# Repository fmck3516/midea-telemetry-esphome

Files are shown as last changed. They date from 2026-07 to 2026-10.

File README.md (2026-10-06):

# midea-telemetry-esphome

An [ESPHome](https://esphome.io/) component to feed test-port telemetry from Midea mini-splits and centrally ducted units into Home Assistant. No Home Assistant? It works standalone too: the dongle serves its own web dashboard and JSON API, with an optional InfluxDB + Grafana stack for long-term history.

It supports a variety of brands including MRCOOL, Cooper&Hunter, Pioneer, and Senville.

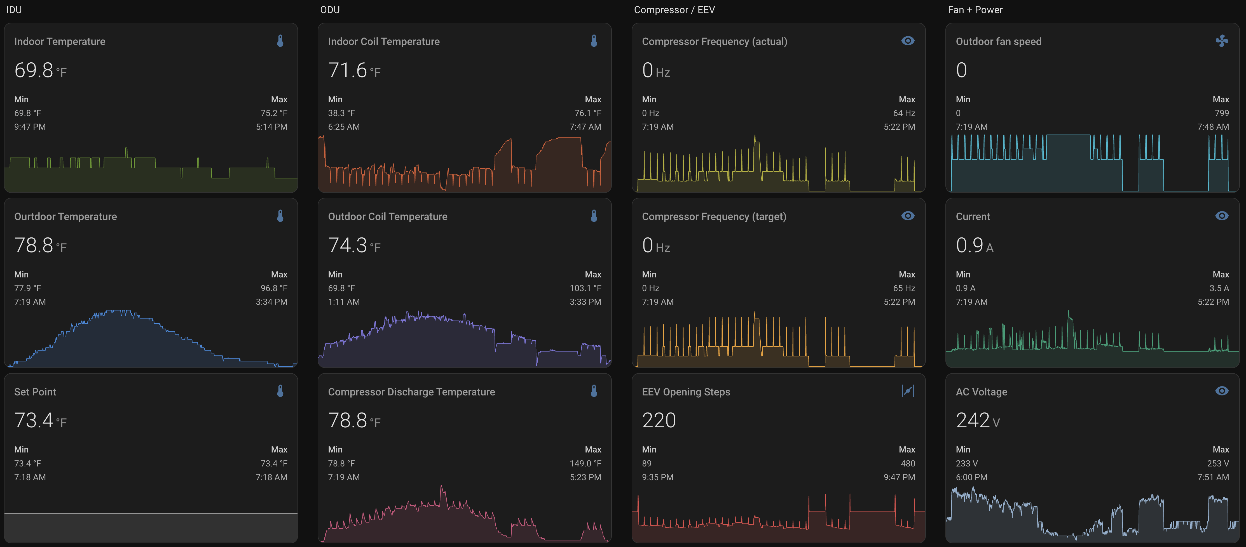
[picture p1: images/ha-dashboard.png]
Home Assistant Dashboard


## Support

Please use [GitHub Issues](https://github.com/fmck3516/midea-telemetry-esphome/issues) for bug reports and feature requests. 
For questions and general discussion, join the [Home Assistant Community thread](https://community.home-assistant.io/t/1015912). I'm active there.

## Compatibility

The dongle has been tested successfully with the following outdoor units:

| Brand | Outdoor Models | Type | 
|---|---|---|
| MRCOOL | DIY-12-HP-C-115C25 | single-zone mini-split |
| Cooper&Hunter | CH-HPR06F9-230VO, CH-N36LCU-230VO | single-zone mini-split |
| Senville | SENDC-36-HF-OG | centrally ducted unit |
| Pioneer | YN018GMFI20RPD | single-zone mini-split |
| ACiQ | ES-48Z-M6C | multi-zone mini-split |

Since Midea-made mini-splits and centrally ducted units are very similar across brands, many other units from brands like MRCOOL, Cooper&Hunter, Senville, Pioneer, Blueridge, etc. are supported as well. To confirm, look for a test port (a 4-pin JST connector labeled `TEST`) on your unit's wiring diagram or on the outdoor unit's control or auxiliary board.

**Multi-zone units:** the dongle runs on multi-zone systems, but four sensors (T1, T2, TT, Pr) have come back empty on the ACiQ multi-zone unit.

## Hardware

All you need is a **dual-core ESP32** and a level shifter. A dual core is required because the bus bit-banging runs in a dedicated FreeRTOS task. A full request/response cycle keeps the bus busy for ~380 ms, far too long to run on the main loop.

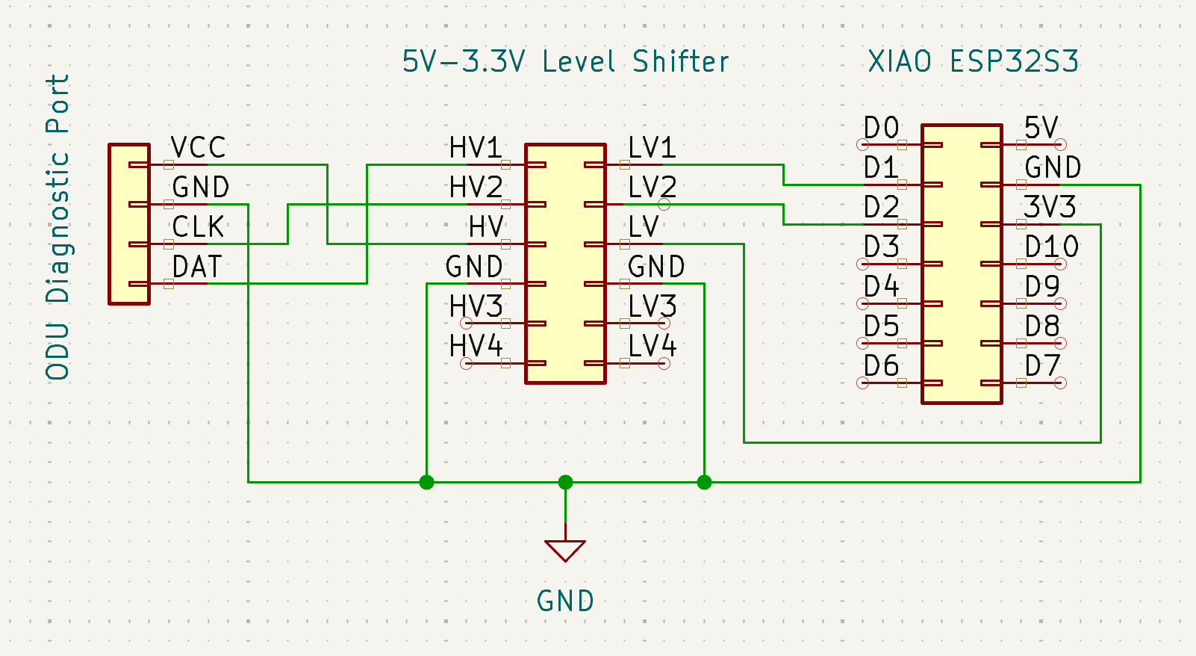
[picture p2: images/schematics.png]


Recommended hardware:
- [XIAO ESP32S3](https://www.amazon.com/dp/B0BYSB66S5)
- [3.3V–5V Level Shifter](https://www.amazon.com/dp/B07F7W91LC)

I used the following connector kits, but you can get away with a single 4-pin male JST-XH connector:
- [XH 2.54mm Connector Kit](https://www.amazon.com/dp/B08G18PWQ6)
- [2.54mm Connector 4 Pin Male Adapter Right Angle](https://www.amazon.com/dp/B0BMDQLR4Q)

### PCB & Enclosure

The KiCad project, schematic, and Gerber files live in [pcb/](pcb/) - a 2-layer board, 41.5 × 22 mm, 1.6 mm thick, with four M2 mounting holes. You solder in just three parts - the ODU connector, the level-shifter module, and the XIAO - and that's the whole build. FreeCAD sources plus STL and 3MF exports for the 3D-printable enclosure are in [enclosure/](enclosure/).

| PCB (top)  | PCB (bottom)  |
| --- | --- |
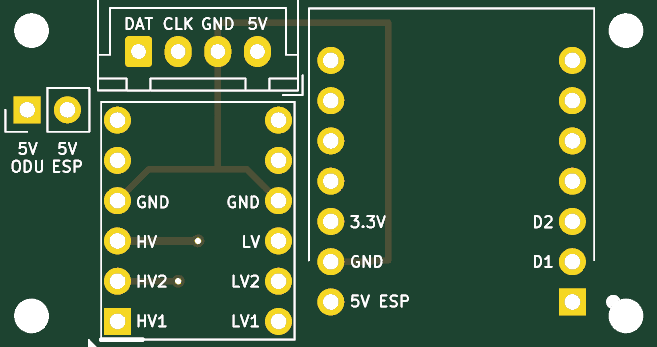
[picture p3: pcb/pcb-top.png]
Top
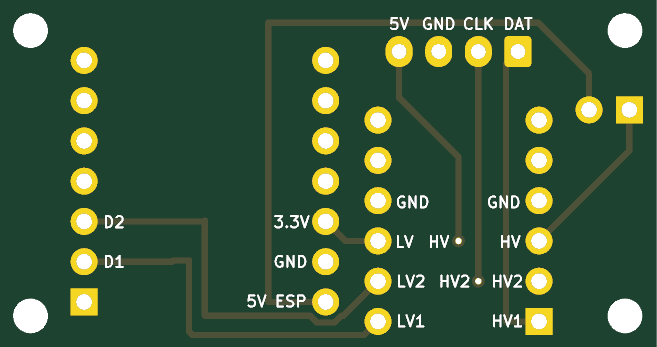
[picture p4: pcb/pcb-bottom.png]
Bottom
|  |  |

| Assembled dongle | Enclosure |
| --- | --- |
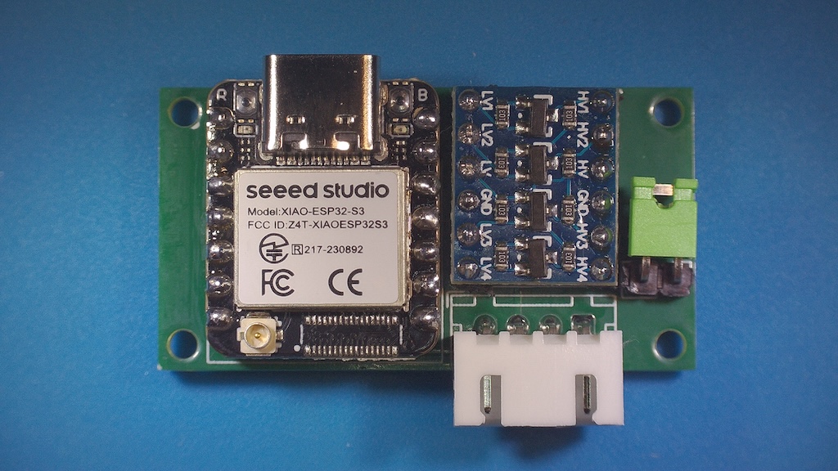
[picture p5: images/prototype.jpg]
Prototype
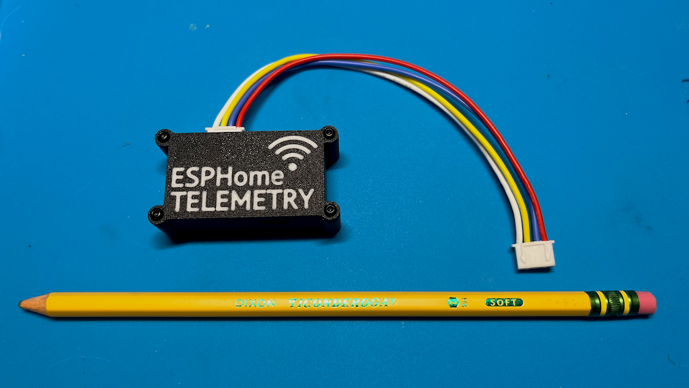
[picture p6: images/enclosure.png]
Enclosure
|  |  |

I've added a jumper that ties the test port's +5V to the XIAO's 5V pin. Use the jumper to run the board straight off the ODU with no USB cable. Leave it off if the board is connected to USB. I also recommend the use of a USB isolator since ground on the test port is not referenced to earth.

## Safety

The outdoor unit runs on mains voltage, and internal capacitors can retain a dangerous charge after being unplugged. Always

- turn off the breaker,
- pull the disconnect, and
- wait several minutes and/or verify capacitors are discharged

before performing the installation. Wear appropriate PPE. Consult a qualified electrician when in doubt.

## Installation

*(See [Safety](#safety) first if you're jumping straight to this section.)*

Remove the top panel of the ODU. You'll see the control board. Remove the screws securing the control board to the ODU, then detach the cables from the cable clamps so you can lift the board for access — there's no need to unplug the cables themselves. The test port on my units is located at the front of the board. Plug in the dongle, with the red wire facing toward you. Reattach the cables to the cable clamps and secure the board back to the ODU. There should be enough clearance to tuck the dongle into the service panel — this lets you access the dongle later without needing to remove the control board again. Reinstall the top panel.

| Control board | Test port |
| --- | --- |
| Install 1/4 | Install 2/4 |

| Dongle plugged in | Dongle tucked into service panel |
| --- | --- |
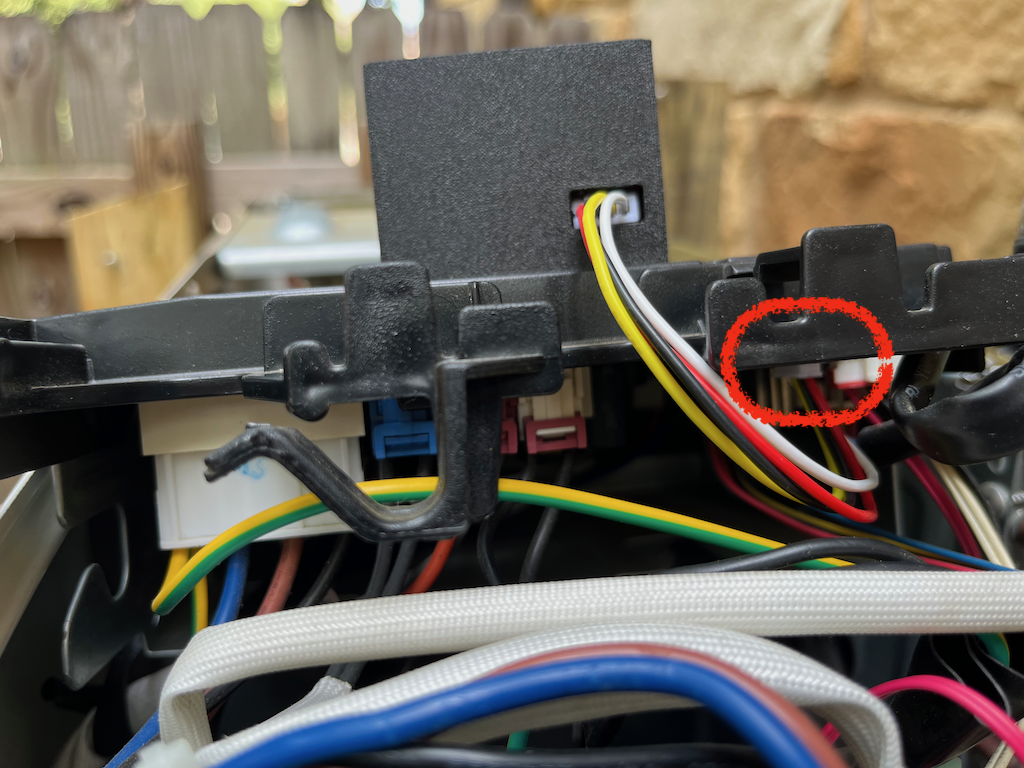
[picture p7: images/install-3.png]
Install 3/4
|  | Install 4/4 |

For a visual walkthrough, see [this installation video](https://www.youtube.com/watch?v=poEmSZnrnjs).

## First use

Upon first start, the dongle brings up a temporary WiFi hotspot so you can connect it to your WiFi network. Join the `midea-telemetry-esphome` network (password `midea-telemetry-esphome`) and provide your WiFi network's SSID and password in the popup that appears. Once connected, the dongle serves a webserver at `http://midea-telemetry.local` (useful if you don't run Home Assistant), and Home Assistant automatically detects it as a new ESPHome device.

| WiFi hotspot | WiFi setup |
| --- | --- |
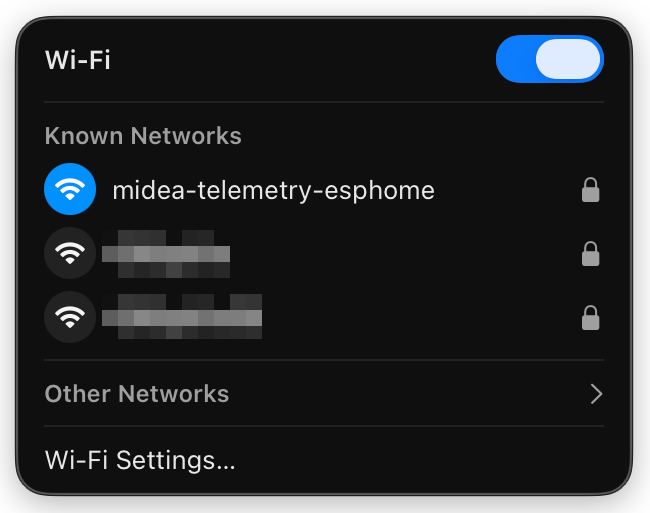
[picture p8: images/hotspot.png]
Hotspot
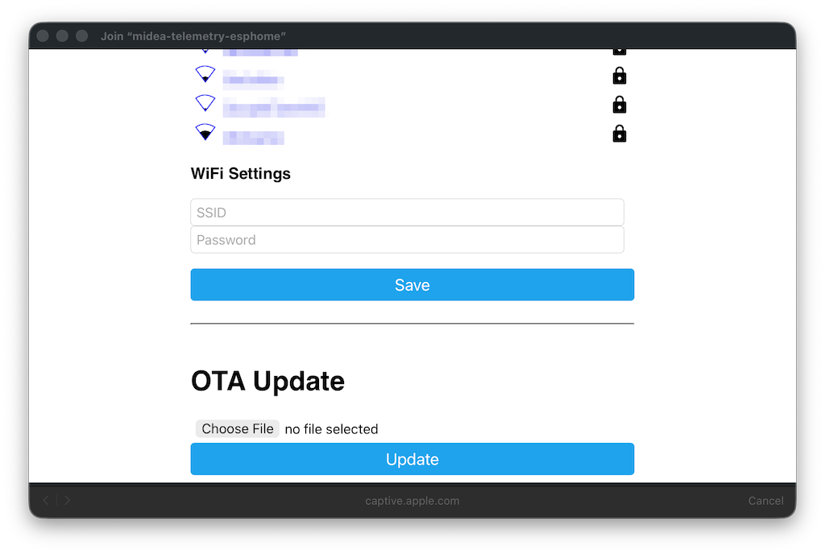
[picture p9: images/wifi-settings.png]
Wi-Fi settings
|  |  |

| On-board webserver | Home Assistant auto-discovery |
| --- | --- |
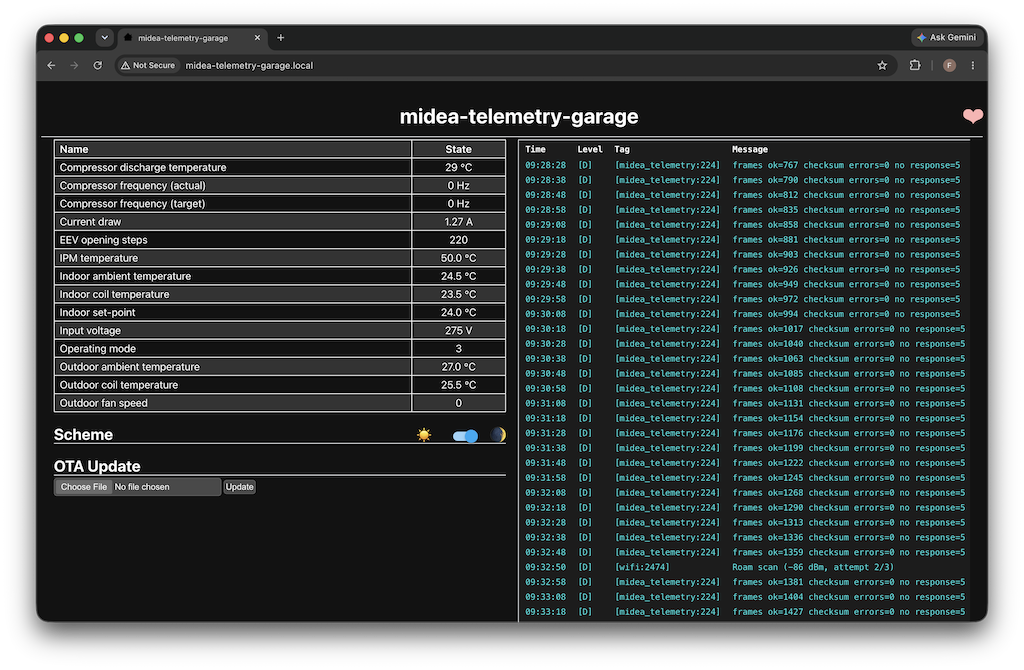
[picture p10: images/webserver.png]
Webserver
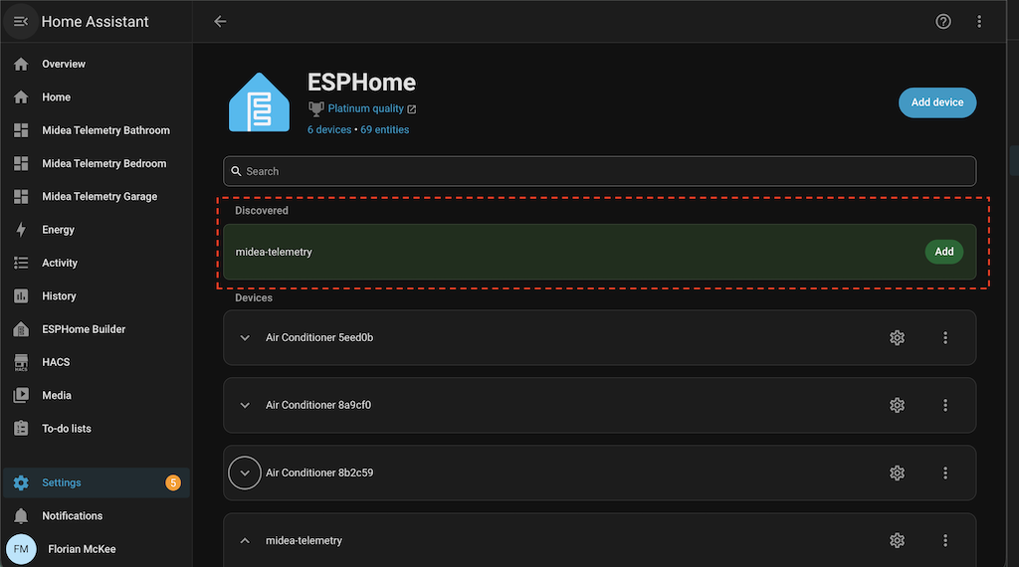
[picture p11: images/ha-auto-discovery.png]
Device auto discovery
|  |  |

## Configuration

See [example_midea_telemetry.yaml](example_midea_telemetry.yaml) for a complete configuration with every supported sensor. That file uses a local `components:` source, so it's flashable straight from a checkout of this repo; to pull the component remotely instead, switch the source to `github://fmck3516/midea-telemetry-esphome`.

## Flashing

Flash your ESP32 with `esphome`. On macOS:

```sh
brew install esphome
esphome run example_midea_telemetry.yaml
```

## Supported Sensors

The following sensors are currently supported. `Code` is the two-letter parameter code the Midea
service manuals use for the same value, so a reading here can be matched against the one the unit
shows on its own diagnostic display; `—` means the manuals define no code for that value.

| Code | Name | Unit |
|---|---|---|
| TT | `indoor_setpoint` | °C |
| T1 | `indoor_ambient_temperature` | °C |
| T2 | `indoor_coil_temperature` | °C |
| T3 | `outdoor_coil_temperature` | °C |
| T4 | `outdoor_ambient_temperature` | °C |
| TP | `discharge_temperature` | °C |
| — | `ipm_temperature` | °C |
| — | `operating_mode` | raw |
| oT | `compressor_frequency_indoor_target` | Hz |
| FT | `compressor_frequency_outdoor_target` | Hz |
| Fr | `compressor_frequency_actual_int` | Hz |
| Fr | `compressor_frequency_actual_float` | Hz |
| — | `compressor_frequency_outdoor_control` | Hz |
| Pr | `outdoor_fan_speed` | RPM |
| Lr | `eev_steps` | raw |
| dL | `current_draw` | A |
| Ac | `input_voltage` | V |
| Uo | `dc_bus_voltage` | V |
| — | `error_code_1` | bit mask for `E3, E0, P8, Eb, P6, PA, L3, L0` |
| — | `error_code_2` | bit mask for `E60, E61, L2, E2, E1, L1, P90, P91` |
| — | `error_code_3` | bit mask for `E80, E81, E1, E83, P0, P1, E5, P8` |
| — | `error_code_4` | bit mask for `P4, P6, PA, L5, L3, L2, E7` |

[FRAME-BYTES.md](FRAME-BYTES.md) documents each sensor in great detail.

## JSON endpoint

Add `expose_json_endpoint: true` to serve all mapped sensors and the underlying raw data as JSON. It needs the `web_server` component:

```yaml
web_server:
  port: 80

midea_telemetry:
  clk_pin: GPIO3
  dat_pin: GPIO2
  expose_json_endpoint: true
```

The endpoint is served at `/json` (e.g. `http://midea-telemetry.local/json`), independent of Home Assistant. This is useful for reverse engineering, scripting, and for using the device without Home Assistant.

## Long-term history (InfluxDB + Grafana)

For a permanent, Home-Assistant-independent history, [`influxdb-grafana/`](influxdb-grafana/) provides a ready-to-run Docker stack: Telegraf polls each dongle's `/json` endpoint and stores the raw frame bytes in InfluxDB v2, and Grafana decodes them into a provisioned dashboard. See [influxdb-grafana/README.md](influxdb-grafana/README.md).

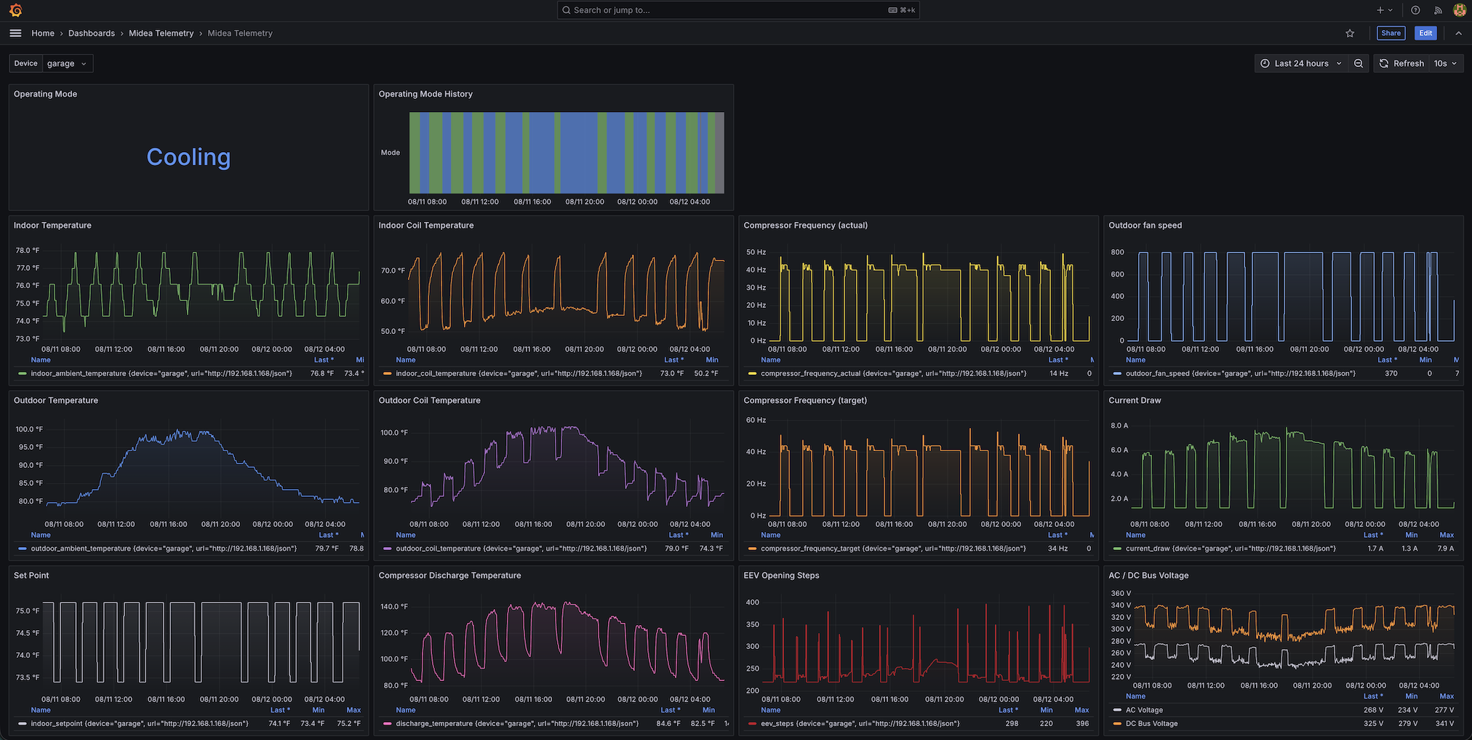
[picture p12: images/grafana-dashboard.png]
Grafana Dashboard


## Prior Art

I've documented the test-port protocol in great detail on Medium: [Reverse Engineering Midea's ODU Diagnostic Port](https://medium.com/@florian.mckee/reverse-engineering-mideas-odu-diagnostic-port-af603e159053). The firmware in this repository is based on those findings. Start there if you want to understand the protocol; the byte mappings and conversion formulas in the [Supported Sensors](#supported-sensors) table come straight from it.

## Warranty

This is a hobby project. I've permanently installed the telemetry module on all of my units without any problems. That said, use it at your own risk. I do not assume any liability if it causes damage to your equipment. See [LICENSE](LICENSE) for additional information.

## Disclaimer

Midea is a trademark of Midea Group. This is an independent, unofficial hobby project and is not affiliated with, authorized, endorsed by, or sponsored by Midea. The name is used only to describe which hardware the project interoperates with. All product names and trademarks are the property of their respective owners.

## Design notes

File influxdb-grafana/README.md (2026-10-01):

# InfluxDB + Grafana stack

A self-contained, permanent history for your midea-telemetry dongles. Telegraf
polls each dongle's `/json` endpoint and writes the **raw frame bytes** into
InfluxDB v2. Grafana decodes them into a provisioned dashboard. No Home
Assistant required.

```
 dongle /json  ──▶  Telegraf  ──▶  InfluxDB v2  ──▶  Grafana
 (every 10 s)     (raw bytes)    (bucket: midea)    (decodes in Flux)
```

## Prerequisites

- Docker with **Compose v2**, the `docker compose` plugin. Check with
  `docker compose version`. The old Python `docker-compose` 1.x is
  unmaintained and crashes with `KeyError: 'ContainerConfig'` whenever it
  recreates a container on current Docker Engine versions, such as when
  upgrading an image. On Ubuntu, install `docker-compose-v2`, or
  `docker-compose-plugin` from Docker's own apt repository.
- Each dongle built with `expose_json_endpoint: true` (pulls in `web_server`),
  reachable on your network. See the [main README](../README.md#json-endpoint).

## Setup

1. **Configure secrets.** Copy the env template and edit it — set a real Influx
   token and passwords:

   ```bash
   cp .env.example .env
   # generate a token:  openssl rand -hex 32
   ```

2. **List your dongles, then generate `telegraf.conf`.** Edit the `DEVICES`
   array at the top of [`gen-telegraf-conf.sh`](gen-telegraf-conf.sh) — one
   `"<url> <device-tag>"` per line — and run:

   ```bash
   ./gen-telegraf-conf.sh > telegraf.conf
   ```

   > ⚠️ **Required before step 3.** `telegraf.conf` is generated and
   > git-ignored (it holds your dongles' addresses), so a fresh clone does not
   > have one. Docker bind-mounts it, and if the file is missing it silently
   > creates a *directory* of that name — after which telegraf fails to start.
   > If that happens: `rm -rf telegraf.conf`, generate it, and bring the stack
   > back up.

   > ⚠️ **mDNS caveat.** Inside a bridged Docker container, `*.local` names do
   > **not** resolve. Use each dongle's **IP address** in `DEVICES`
   > (e.g. `http://192.168.1.42/json`), or — on a Linux host only — uncomment
   > `network_mode: host` for the telegraf service in `docker-compose.yml` to
   > share the host's mDNS resolver. Assign the dongles static DHCP leases so
   > the IPs stay put.

3. **Start it.**

   ```bash
   docker compose up -d
   ```

4. **Open Grafana** at http://localhost:3000, or `http://<host>:3000` from
   another machine on your network (log in with the Grafana
   credentials from `.env`). The **Midea Telemetry** dashboard is already there
   under the *Midea Telemetry* folder, with a **Device** dropdown at the top.

## What's provisioned

| Piece | Where |
|---|---|
| InfluxDB datasource (Flux) | `grafana/provisioning/datasources/influxdb.yml` |
| Dashboard provider | `grafana/provisioning/dashboards/dashboards.yml` |
| Dashboard | `grafana/dashboards/midea-telemetry.json` |

The dashboard charts every sensor from the [Supported Sensors table](../README.md#supported-sensors):
coil/ambient temps, discharge & IPM temps, the compressor-frequency family
(indoor/outdoor target, actual as int and float, and outdoor control),
outdoor fan speed & EEV
steps, input/DC-bus voltage, current draw, and set-point/operating mode. Below
those sit the [error codes](#error-codes), the "Compressor Frequency (extended)"
row (collapsed by default) and the [byte explorer](#byte-explorer). Everything
is filtered by the selected device.

The dashboard refreshes every 5 minutes. Telegraf still polls every 10 s, so
pick a shorter interval from Grafana's refresh dropdown when you want to watch
changes live.

## Network access

| Service | Reachable from | Port |
|---|---|---|
| Grafana | any machine on your network | `3000` |
| InfluxDB | this host only (`127.0.0.1`) | `8086` |
| Telegraf | nowhere, nothing is published | — |

Telegraf and Grafana reach InfluxDB over the compose network at
`http://influxdb:8086`, so InfluxDB doesn't need to be on your network. Its UI
and `tools/export-dashboard-data.py` still work on the host itself, where
`localhost:8086` is available. Run the export tool there.

Don't rely on a host firewall such as `ufw` to close a published port. Docker
adds its own firewall rules for published ports, and they bypass `ufw`. The
binding in `docker-compose.yml` decides who can connect.

To reach InfluxDB from another machine anyway, change its port to
`"8086:8086"` and run `docker compose up -d influxdb`. That exposes InfluxDB's
API and UI to your whole network.

Grafana answers anything that can reach the host on port 3000. Don't forward
that port on your router.

## How the dashboard decodes bytes

### What is stored

Telegraf writes one measurement, `midea_raw`, tagged by `device`. Each field is
one byte of one response frame, named `<frame>_<byte>`:

| Field | Meaning |
|---|---|
| `0x00_2` | response `0x00`, byte 2 |
| `0x05_2` | response `0x05`, byte 2 |
| … | bytes 2–8 of all seven responses, 49 fields |

Bytes 0, 1 and 9 are framing (header, response type, checksum) and are not
stored. What each byte means is documented in [FRAME-BYTES.md](../FRAME-BYTES.md).

Every byte comes from the same `/json` request, so all 49 share one timestamp.
That is what lets a value combine bytes from different frames, like the
compressor frequency float (`0x02[3]` + `0x05[2]`) or the current-draw gate on
`0x02[3]`.

The `dedup` processor drops a scrape in which no byte changed, and passes one
through at least every 5 minutes. Charts of a steady value therefore have fewer
points, not gaps.

> **Why one config entry per byte?** Two simpler Telegraf configs fail
> silently: the classic `json` parser drops arrays of plain numbers and writes
> nothing, and json_v2's `object` parser collapses each frame's array into one
> field that keeps only the last element (the checksum). Naming each byte is
> deterministic.

### How a panel decodes

Each panel's query:

1. filters to the bytes it needs;
2. has InfluxDB keep only the **last sample per chart window** (the stat cards
   keep only the latest sample; the [error-code panels](#error-codes) keep the
   window's highest sample instead, for the reason given there);
3. pivots those samples into one row per timestamp;
4. applies the formula from the byte's block in
   [FRAME-BYTES.md](../FRAME-BYTES.md);
5. names the result after the firmware sensor, so legends and exported CSV
   columns keep the sensor names.

Step 2 has to come before the pivot. Up to that point InfluxDB's storage
engine runs the query itself. From the pivot on, every row is processed one at
a time, and doing that for every raw point kept `influxd` at about four CPU
cores while the dashboard still refreshed every 10 s.

It keeps the *last* sample rather than the average because all 49 bytes of a
scrape are written together. The last sample of each byte in a window therefore
comes from the same scrape, so the two halves of a 16-bit value, and a reading
and its current-draw gate, always belong together. Averaging each byte on its
own would mix scrapes.

For example, `indoor_ambient_temperature`:

```flux
import "math"

from(bucket: "${bucket}")
  |> range(start: v.timeRangeStart, stop: v.timeRangeStop)
  |> filter(fn: (r) => r._measurement == "midea_raw" and r.device == "${device}")
  |> filter(fn: (r) => r._field == "0x00_2")
  |> aggregateWindow(every: v.windowPeriod, fn: last, createEmpty: false)
  |> pivot(rowKey: ["_time"], columnKey: ["_field"], valueColumn: "_value")
  |> filter(fn: (r) => exists r["0x00_2"])
  |> map(fn: (r) => {
        b = float(v: r["0x00_2"])
        // NTC β-model, rounded to the nearest 0.5 °C; 0 and 255 are fault codes
        ntc = (b) => math.round(x: (1.0 / (1.0 / 298.15 + math.log(x: 0.81 * (255.0 - b) / b) / 4150.0) - 273.15) * 2.0) / 2.0

        return {_time: r._time, _field: "indoor_ambient_temperature", _value: if b == 0.0 then -66.0 else if b == 255.0 then 255.0 else ntc(b: b)}
     })
  |> group(columns: ["_field"])
  |> sort(columns: ["_time"])
  |> map(fn: (r) => ({ r with _value: r._value * 1.8 + 32.0 }))
```

Because the formula lives in the query, fixing a decode needs no reflash. The
whole history is recomputed the next time the panel loads.

**Keep the decodes in step with the firmware.** Home Assistant and the dongle's
own web page still use the firmware's decode, so the same formula exists in two
places. A decode change updates both, plus
[FRAME-BYTES.md](../FRAME-BYTES.md#keeping-this-file-current).

Known differences from the firmware:

- **Charts show the last reading in each window**, not the average. The two
  only differ when a window spans several scrapes, which happens when zoomed
  far out.
- **Current draw** is 0.01 A higher on six raw values (10, 30, 70, 130, 140,
  150). The firmware computes in float32, lands just under a whole hundredth
  and truncates. Flux computes in float64 and gets the exact value. Every
  other decode matches the firmware for all 256 byte values.
- **Stale frames** show as a flat line, not a gap. The firmware reports a
  decoded sensor as unavailable once its frame is 60 s old. `/json` keeps
  serving the last raw frame received.

### Error codes

The **Error Codes** row charts each error bit field of response `0x02` over
time, one panel per byte, titled with the codes that byte carries:

| Panel | Byte | Sensor |
|---|---|---|
| Error Code E3, E0, P8, Eb, P6, PA, L3, L0 | `0x02[4]` | `error_code_1` |
| Error Code E60, E61, L2, E2, E1, L1, P90, P91 | `0x02[5]` | `error_code_2` |
| Error Code E80, E81, E1, E83, P0, P1, E5, P8 | `0x02[6]` | `error_code_3` |
| Error Code P4, P6, PA, L5, L3, L2, E7 | `0x02[7]` | `error_code_4` |

Charts rather than single values, so a fault can be lined up in time against
the temperature, frequency and current panels above — a `P0` means more once
you can see what the compressor was doing in the minutes before it. The legend
carries last/min/max, so the worst value over the selected range is readable
without hunting along the line.

The codes are listed from bit 0 (value 1) up to bit 7 (value 128), so a panel
reading `20` has bits 2 and 4 set — the third and fifth code in its title.
[FRAME-BYTES.md](../FRAME-BYTES.md#response-type-0x02) spells out every bit.

**These four panels keep the highest sample per window**, not the last one
like every other panel. A bit field is not a quantity: averaging or taking the
last sample of a window would hide a fault that set and cleared inside it, and
an average would invent byte values that never occurred (a window holding `0`
and `16` would read `8`, which is a different code entirely). `max` always
reports a byte that was really seen.

The row is **expanded by default**: a fault that came and went is easy to miss
behind a collapsed row. On a healthy unit all four charts stay flat at `0`, so
collapse it if you would rather have the vertical space.

### Byte explorer

The bottom of the dashboard charts undecoded bytes, for hunting new mappings.
Two variables drive it:

| Variable | Values |
|---|---|
| `Message` (`frame`) | `0x00` … `0x06` |
| `Byte` (`byte`) | `2` … `8` |

A repeating **Message** row per response frame holds one chart per byte, four
to a line, each titled like **`0x00[2]`**. Narrow either dropdown to focus on
one message, or on the same byte across all messages.

## Export the dashboard data

[`tools/export-dashboard-data.py`](../tools/export-dashboard-data.py) writes the
data behind **every chart on the dashboard** to CSV — one file per chart, per
device — for the last *N* days:

```bash
./tools/export-dashboard-data.py --days 7
```

```
exports/2025-08-30T09-14-02/
├── manifest.json                  # panel → file, columns, and the Flux run
├── bedroom/
│   ├── t1-indoor-temperature.csv  # time,indoor_ambient_temperature
│   ├── mode-set-point.csv         # multi-target panels get one column each
│   └── 0x00-2.csv                 # byte explorer charts too
└── garage/…
```

It reads the queries out of `grafana/dashboards/midea-telemetry.json` and runs
them against InfluxDB directly, so Grafana does not have to be up — only
InfluxDB. Credentials come from `.env` (override with `$INFLUX_*` or the flags).
Standard library only; no `pip install`.

| Flag | Default |
|---|---|
| `--days N` | `7` — how far back to export (fractional days are fine) |
| `--device TAG` | every device in the bucket; repeatable |
| `--interval` | `auto` (~2000 points/series); set `1m`, `5m`, … to fix it |
| `--out DIR` | `tools/exports/<timestamp>` |
| `--dry-run` | print the Flux queries instead of running them |

The hidden per-panel target that pins the Y axis to zero (the `${ymin}` helper)
is skipped — it carries no data.

## Verify data is flowing

```bash
docker compose logs -f telegraf     # should show no connection errors
```

On the host, in the InfluxDB UI (http://localhost:8086) → *Data Explorer*, query the `midea`
bucket for measurement `midea_raw`. You should see fields `0x00_2` … `0x06_8`,
tagged by `device`. Or list the field keys in the script editor:

```flux
import "influxdata/influxdb/schema"

schema.measurementFieldKeys(bucket: "midea", measurement: "midea_raw")
```

## Retention

`INFLUX_RETENTION` in `.env` controls how long data is kept (`0s` = forever).
Change it before first boot, or adjust the bucket's retention later in the
InfluxDB UI.

## Common tweaks

- **Poll interval:** `interval` in the `[agent]` block of
  `gen-telegraf-conf.sh`, then regenerate. Keep it ≥ the dongle's
  `update_interval` so you're not polling faster than new frames arrive.
- **Change the bucket name:** update `INFLUX_BUCKET` in `.env` **and** the hidden
  `bucket` constant in the dashboard (Dashboard settings → Variables → `bucket`).
- **Add/remove a dongle:** edit `DEVICES` in `gen-telegraf-conf.sh`, then
  `./gen-telegraf-conf.sh > telegraf.conf && docker compose restart telegraf`.
  New devices appear in the dropdown automatically.
- **Change a decode:** edit the panel's Flux in
  `grafana/dashboards/midea-telemetry.json`, and keep it in step with the
  firmware (see [How a panel decodes](#how-a-panel-decodes)).

## Reset

```bash
docker compose down          # stop, keep data
docker compose down -v       # stop and delete all stored data
```

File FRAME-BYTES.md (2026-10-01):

# Frame bytes

What every byte of every test-port message means, as far as it is known, and how the decoded
ones are converted. The [Supported Sensors](README.md#supported-sensors) table in the README only
lists the sensors. Look here for which bytes a sensor comes from, or what an unmapped byte like
[`0x03[4]`](#payload-0x034) might be.

Bytes are written `0x<type>[<index>]`, the notation used by the README, `/json`, the Grafana
byte explorer and the [raw byte sensors](README.md#raw-frame-bytes-optional). The index is
0-based within the 10-byte frame.

## Byte map

Every response byte at a glance, by response type (rows) and byte index (columns). Each cell links
to the block that describes the byte.

| Type | 0 | 1 | 2 | 3 | 4 | 5 | 6 | 7 | 8 | 9 |
|---|:-:|:-:|:-:|:-:|:-:|:-:|:-:|:-:|:-:|:-:|
| [`0x00`](#response-type-0x00) | [F](#frame-layout) | [F](#frame-layout) | [✅](#payload-0x002) | [✅](#payload-0x003) | [✅](#payload-0x004) | [✅](#payload-0x005) | [✅](#payload-0x006) | [✅](#payload-0x007) | [✅](#payload-0x008) | [F](#frame-layout) |
| [`0x01`](#response-type-0x01) | [F](#frame-layout) | [F](#frame-layout) | [✅](#payload-0x012) | [✅](#payload-0x013) | [✅](#payload-0x014) | [✅](#payload-0x015) | [✅](#payload-0x016) | [✅](#payload-0x017) | [🟡](#payload-0x018) | [F](#frame-layout) |
| [`0x02`](#response-type-0x02) | [F](#frame-layout) | [F](#frame-layout) | [✅](#payload-0x022) | [✅](#payload-0x023) | [✅](#payload-0x024) | [✅](#payload-0x025) | [✅](#payload-0x026) | [✅](#payload-0x027) | [✅](#payload-0x028) | [F](#frame-layout) |
| [`0x03`](#response-type-0x03) | [F](#frame-layout) | [F](#frame-layout) | [⬜](#payload-0x032) | [⬜](#payload-0x033) | [🟡](#payload-0x034) | [🟡](#payload-0x035) | [✅](#payload-0x036) | [⬜](#payload-0x037) | [⬜](#payload-0x038) | [F](#frame-layout) |
| [`0x04`](#response-type-0x04) | [F](#frame-layout) | [F](#frame-layout) | [🟡](#payload-0x042) | [⬜](#payload-0x043) | [⬜](#payload-0x044) | [⬜](#payload-0x045) | [🟡](#payload-0x046) | [✅](#payload-0x047) | [✅](#payload-0x048) | [F](#frame-layout) |
| [`0x05`](#response-type-0x05) | [F](#frame-layout) | [F](#frame-layout) | [✅](#payload-0x052) | [🟡](#payload-0x053) | [⬜](#payload-0x054) | [⬜](#payload-0x055) | [⬜](#payload-0x056) | [⬜](#payload-0x057) | [⬜](#payload-0x058) | [F](#frame-layout) |
| [`0x06`](#response-type-0x06) | [F](#frame-layout) | [F](#frame-layout) | [⬜](#payload-0x0620x068) | [⬜](#payload-0x0620x068) | [⬜](#payload-0x0620x068) | [⬜](#payload-0x0620x068) | [⬜](#payload-0x0620x068) | [⬜](#payload-0x0620x068) | [⬜](#payload-0x0620x068) | [F](#frame-layout) |

| Mark | Meaning |
|---|---|
| F | Framing: header, type or checksum. See [Frame layout](#frame-layout) |
| ✅ | Decoded and exposed as a Home Assistant sensor |
| 🟡 | Meaning proposed or partially known, but not exposed as a sensor |
| ⬜ | Unknown |

## Frame layout

Every message, in both directions, is 10 bytes, sent LSB-first:

| Byte | Request (dongle → ODU) | Response (ODU → dongle) |
|---|---|---|
| 0 | `0xAA`, the header for a message from the tester | `0x55`, the header for a message from the ODU |
| 1 | Request type, `0x00`–`0x03` | Response type, `0x00`–`0x06` |
| 2–8 | Payload | Payload |
| 9 | Checksum | Checksum |

**Checksum:** all ten bytes sum to zero modulo 256, so `checksum = (256 − sum(bytes 0–8) % 256) % 256`.
The firmware drops a response that fails this check. A response of ten `0xFF` bytes means the ODU
did not answer.

**Multi-byte values** are little-endian: the lower index is the low byte.

**Requests and responses are not paired.** The ODU steps through the seven response types on its
own, so a response is identified by its type byte, not by the request that triggered it.

## Requests

The dongle replays the four requests of Midea's handheld inverter tester, byte for byte. Their
payloads are constant, and nothing is known about what they mean.

| Type | Frame | Payload |
|---|---|---|
| `0x00` | `AA 00 00 00 00 00 00 00 00 56` | all `0x00` |
| `0x01` | `AA 01 00 00 00 00 00 00 00 55` | all `0x00` |
| `0x02` | `AA 02 00 00 00 00 FF 00 00 55` | all `0x00` except byte 6 = `0xFF` |
| `0x03` | `AA 03 00 00 00 00 00 00 00 53` | all `0x00` |

`0x02[6]` = `0xFF` is the only non-zero payload byte.

## Responses

Bytes 0, 1 and 9 of every response are **framing**, as shown above. The blocks below cover bytes 2–8.

### Response Type `0x00`

Every payload byte of `0x00` is decoded.

#### Payload `0x00[2]`

| | |
|---|---|
| Meaning | Indoor ambient temperature |
| HA Entity | `indoor_ambient_temperature` |
| Midea Code | T1 |
| Encoding | [NTC β-model](#ntc-thermistors) |
| Confidence | High |
| Evidence | Encoding reverse-engineered using Midea's Inverter Tester |
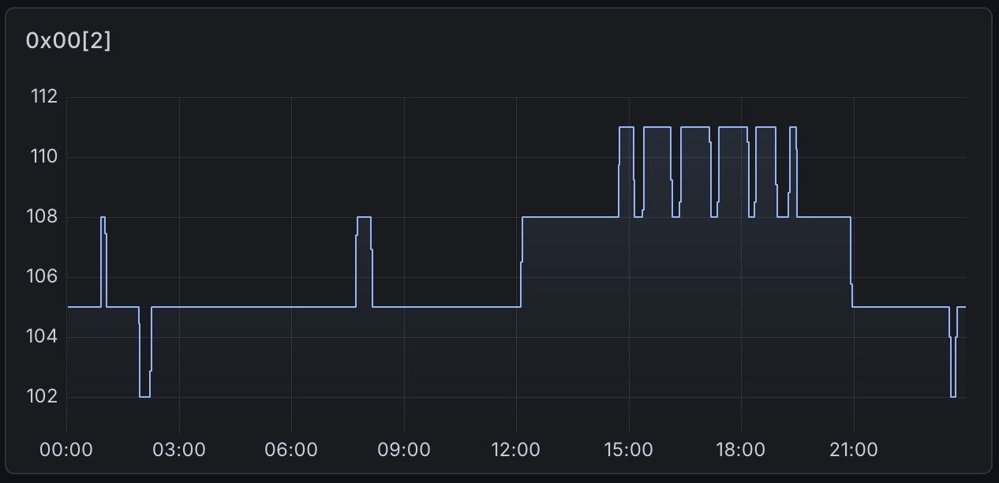
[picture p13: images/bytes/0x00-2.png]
| Chart (raw) |  |

#### Payload `0x00[3]`

| | |
|---|---|
| Meaning | Indoor coil temperature |
| HA Entity | `indoor_coil_temperature` |
| Midea Code | T2 |
| Encoding | [NTC β-model](#ntc-thermistors) |
| Confidence | High |
| Evidence | Encoding reverse-engineered using Midea's Inverter Tester |
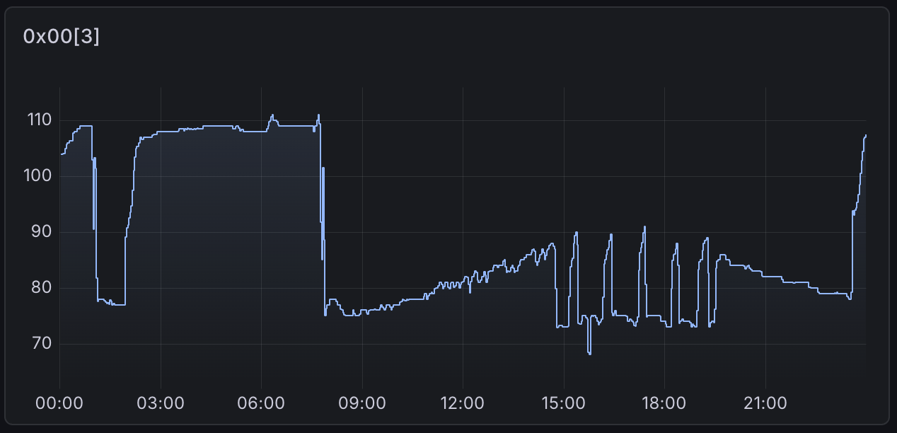
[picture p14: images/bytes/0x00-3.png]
| Chart (raw) |  |

#### Payload `0x00[4]`

| | |
|---|---|
| Meaning | Outdoor coil temperature |
| HA Entity | `outdoor_coil_temperature` |
| Midea Code | T3 |
| Encoding | [NTC β-model](#ntc-thermistors) |
| Confidence | High |
| Evidence | Encoding reverse-engineered using Midea's Inverter Tester |
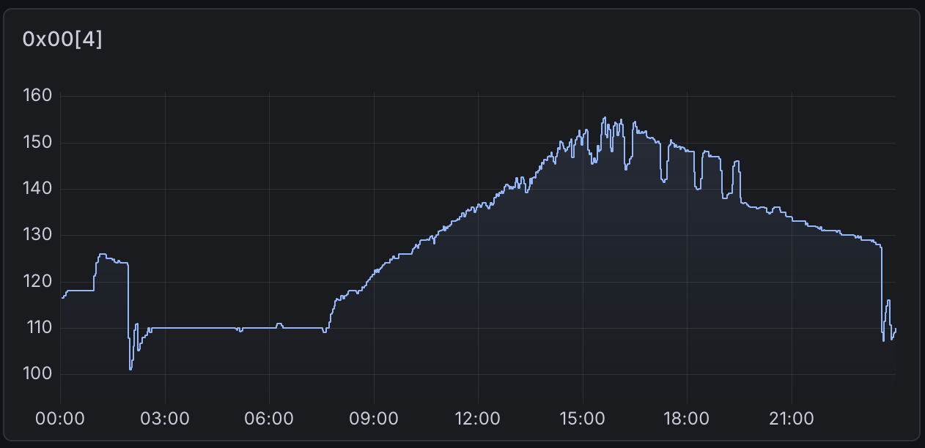
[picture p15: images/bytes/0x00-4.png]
| Chart (raw) |  |

#### Payload `0x00[5]`

| | |
|---|---|
| Meaning | Outdoor ambient temperature |
| HA Entity | `outdoor_ambient_temperature` |
| Midea Code | T4 |
| Encoding | [NTC β-model](#ntc-thermistors) |
| Confidence | High |
| Evidence | Encoding reverse-engineered using Midea's Inverter Tester |
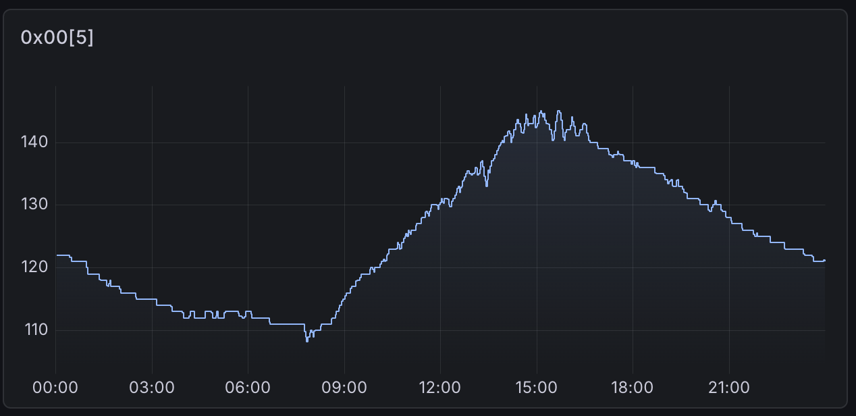
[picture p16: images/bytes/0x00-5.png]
| Chart (raw) |  |

#### Payload `0x00[6]`

| | |
|---|---|
| Meaning | Compressor discharge temperature |
| HA Entity | `discharge_temperature` |
| Midea Code | TP |
| Encoding | [Steinhart–Hart](#discharge-thermistor) |
| Confidence | High |
| Evidence | Encoding reverse-engineered using Midea's Inverter Tester |
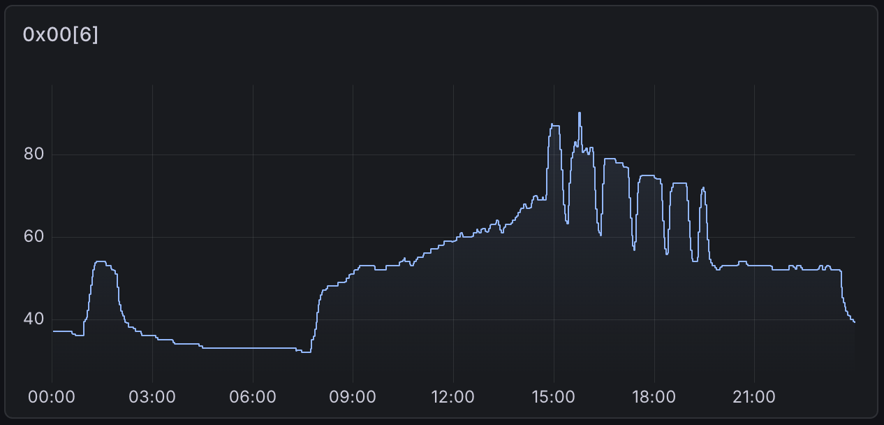
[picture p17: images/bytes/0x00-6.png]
| Chart (raw) |  |

#### Payload `0x00[7]`

| | |
|---|---|
| Meaning | Outdoor fan speed, low byte |
| HA Entity | `outdoor_fan_speed` |
| Midea Code | Pr |
| Encoding | uint16 LE with [`0x00[8]`](#payload-0x008) |
| Confidence | High |
| Evidence | Encoding reverse-engineered using Midea's Inverter Tester |
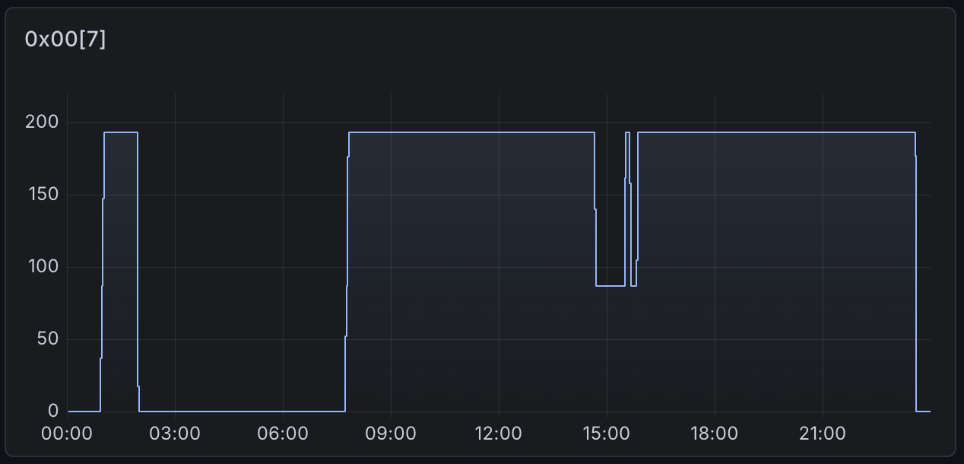
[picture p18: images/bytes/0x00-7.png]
| Chart (raw) |  |

#### Payload `0x00[8]`

| | |
|---|---|
| Meaning | Outdoor fan speed, high byte |
| HA Entity | `outdoor_fan_speed` |
| Midea Code | Pr |
| Encoding | uint16 LE with [`0x00[7]`](#payload-0x007) |
| Confidence | High |
| Evidence | Encoding reverse-engineered using Midea's Inverter Tester |
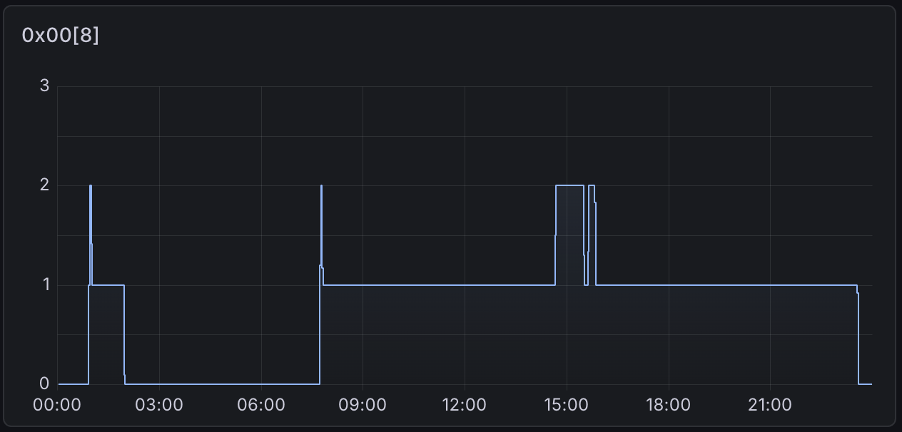
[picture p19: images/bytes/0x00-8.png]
| Chart (raw) |  |

### Response Type `0x01`

#### Payload `0x01[2]`

| | |
|---|---|
| Meaning | Compressor current draw |
| HA Entity | `current_draw` |
| Midea Code | dL |
| Encoding | `0.117 · b + 0.92` A, truncated to 0.01 A, gated on the compressor frequency |
| Confidence | High |
| Evidence | Encoding reverse-engineered using Midea's Inverter Tester. The byte only carries a meaningful current while the compressor runs. When it is stopped (unit OFF or FAN ONLY) the byte sits at a per-unit floor (3 on the 115V MRCOOL, 0 on the 220V Cooper & Hunter) that the formula would misread as ~1 A. So `current_draw` reports a ~0.2 A standby baseline. This is the value I measured with a clamp meter whenever `compressor_frequency_actual_int` (`0x02[3]`) is 0 on my mini-splits. |
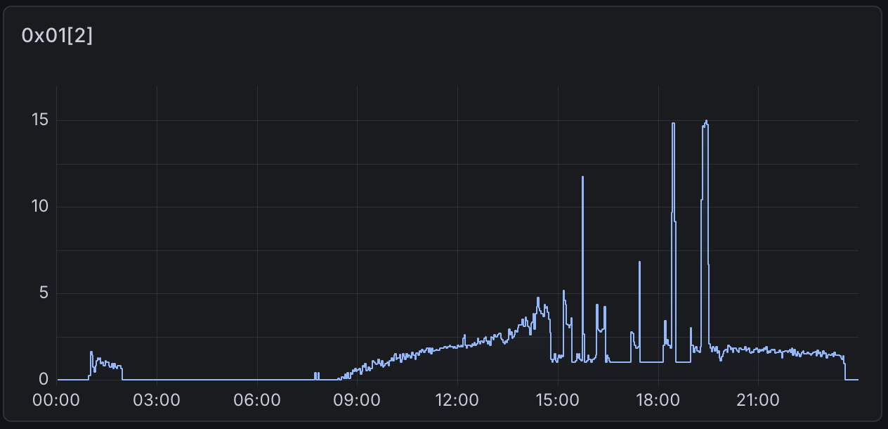
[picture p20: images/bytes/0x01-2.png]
| Chart (raw) |  |

#### Payload `0x01[3]`

| | |
|---|---|
| Meaning | AC input voltage |
| HA Entity | `input_voltage` |
| Midea Code | Ac |
| Encoding | `⌊b · 32/25 + 40⌋` V |
| Confidence | High |
| Evidence | Encoding reverse-engineered using Midea's Inverter Tester. |
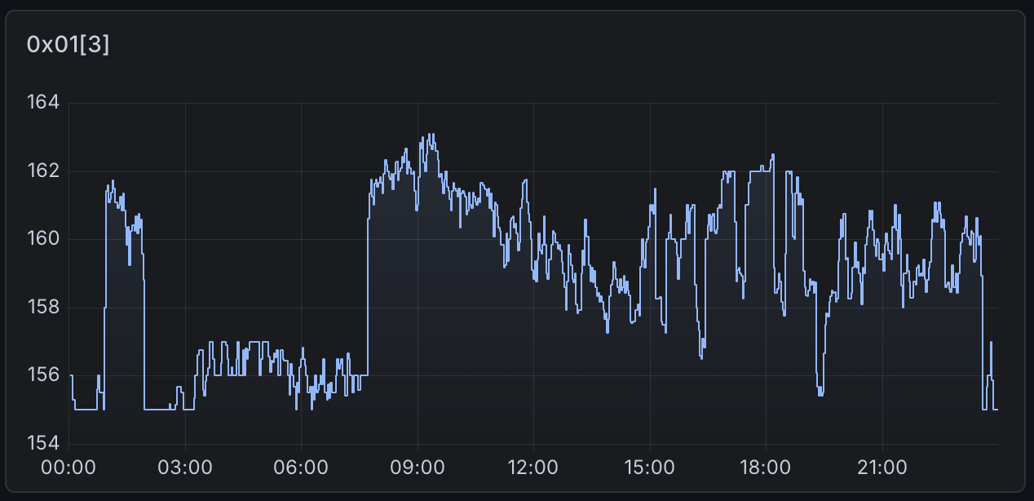
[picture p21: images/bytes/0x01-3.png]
| Chart (raw) |  |

#### Payload `0x01[4]`

| | |
|---|---|
| Meaning | IPM temperature |
| HA Entity | `ipm_temperature` |
| Midea Code | — |
| Encoding | [NTC β-model](#ntc-thermistors) |
| Confidence | Medium |
| Evidence | Not confirmed against a service display. It only seems to carry the IPM temperature on some units: [forum](https://community.home-assistant.io/t/1015912/17), [forum](https://community.home-assistant.io/t/1015912/60), [forum](https://community.home-assistant.io/t/1015912/79) |
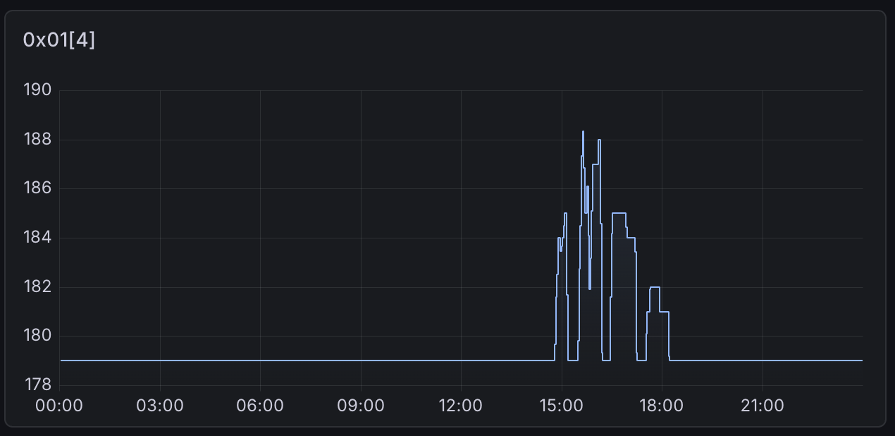
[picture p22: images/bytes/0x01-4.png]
| Chart (raw) |  |

#### Payload `0x01[5]`

| | |
|---|---|
| Meaning | EEV opening steps, low byte |
| HA Entity | `eev_steps` |
| Midea Code | Lr |
| Encoding | uint16 LE with [`0x01[6]`](#payload-0x016) |
| Confidence | High |
| Evidence | Encoding reverse-engineered using Midea's Inverter Tester |
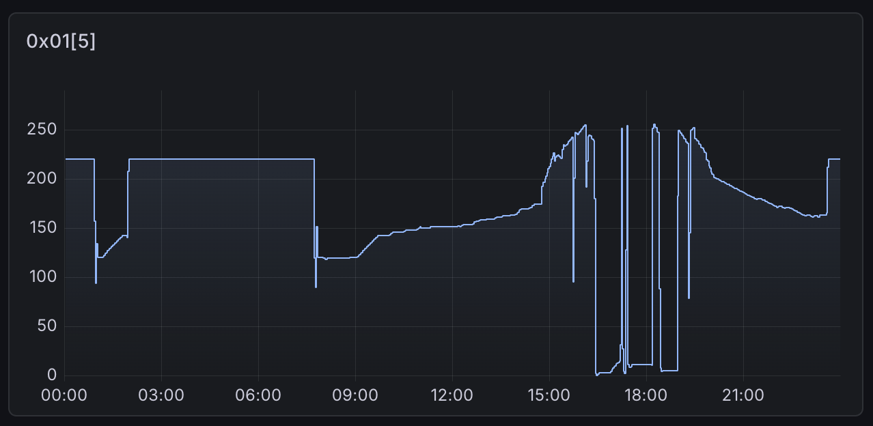
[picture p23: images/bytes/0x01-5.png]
| Chart (raw) |  |

#### Payload `0x01[6]`

| | |
|---|---|
| Meaning | EEV opening steps, high byte |
| HA Entity | `eev_steps` |
| Midea Code | Lr |
| Encoding | uint16 LE with [`0x01[5]`](#payload-0x015) |
| Confidence | High |
| Evidence | Encoding reverse-engineered using Midea's Inverter Tester |
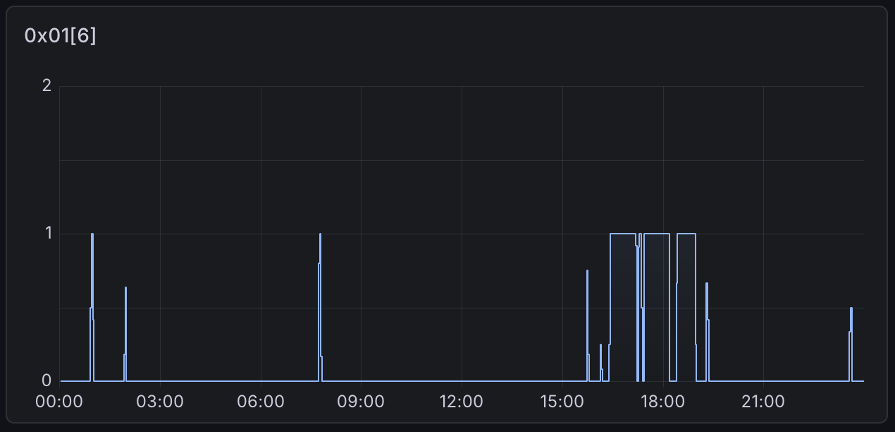
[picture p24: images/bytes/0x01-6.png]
| Chart (raw) |  |

#### Payload `0x01[7]`

| | |
|---|---|
| Meaning | Indoor set-point |
| HA Entity | `indoor_setpoint` |
| Midea Code | TT |
| Encoding | `b < 50 ? b : (b − 50) / 2` °C<br><br>Two OEM encodings, told apart by range:<br>16-32: set-point in °C<br>82-114: set-point in half-degrees °C offset by 50 |
| Confidence | High |
| Evidence | Encoding reverse-engineered using Midea's Inverter Tester + adjustments based on observations from two of my units |
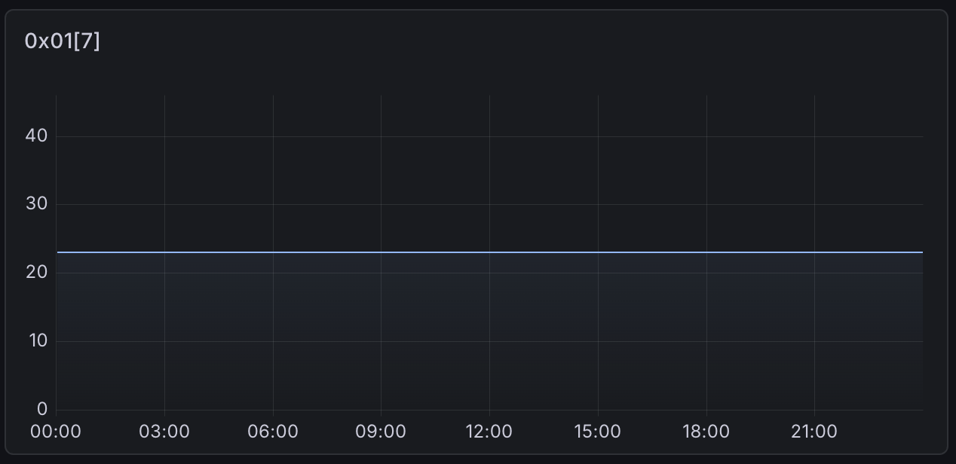
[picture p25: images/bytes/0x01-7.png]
| Chart (raw) |  |

#### Payload `0x01[8]`
https://community.home-assistant.io/t/full-telemetry-for-midea-based-mini-splits-centrally-ducted-units/1015912/108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
| | |
|---|---|
| Meaning | Bit 2: High output flag<br>Bit 1: Compressor on/off<br>Bit 5: permanantely set on one of my units until I toggled the breaker |
| HA Entity | — |
| Midea Code | — |
| Encoding | Bit field |
| Confidence | Low |
| Evidence | [forum](https://community.home-assistant.io/t/1015912/41), [forum](https://community.home-assistant.io/t/1015912/108), [forum](https://community.home-assistant.io/t/1015912/113) |
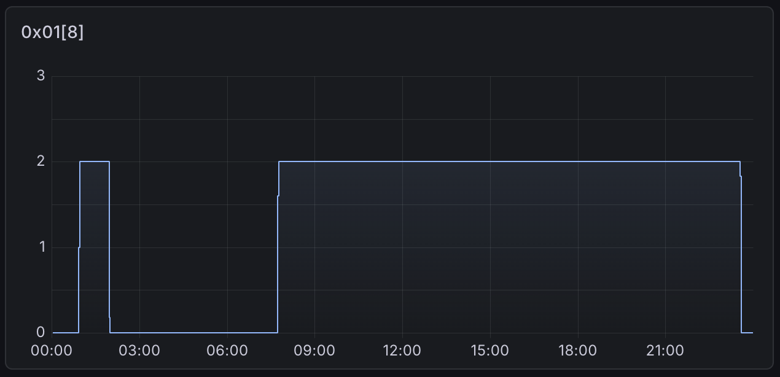
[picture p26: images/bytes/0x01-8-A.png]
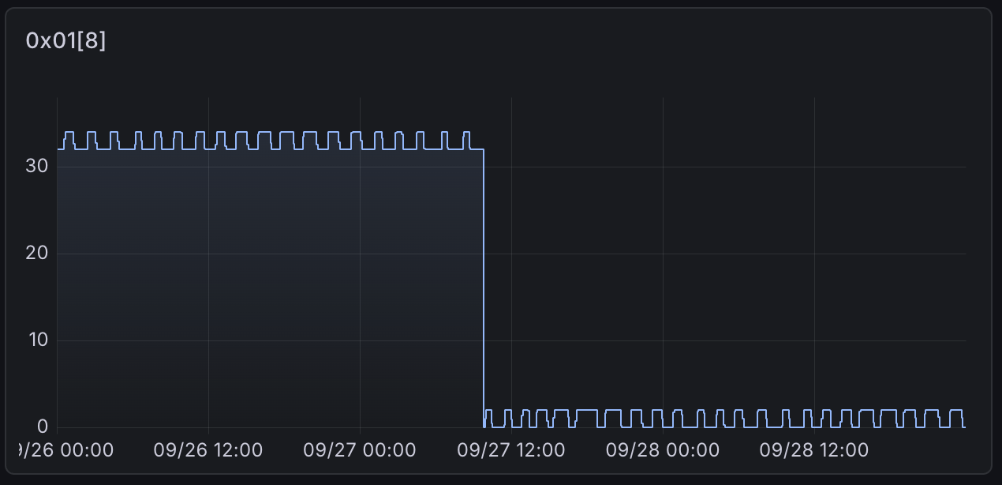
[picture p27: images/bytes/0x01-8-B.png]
| Chart (raw) | <br> |

### Response Type `0x02`

#### Payload `0x02[2]`

| | |
|---|---|
| Meaning | Compressor frequency, outdoor target |
| HA Entity | `compressor_frequency_outdoor_target` |
| Midea Code | FT |
| Encoding | `b` Hz |
| Confidence | High |
| Evidence | Encoding reverse-engineered using Midea's Inverter Tester |
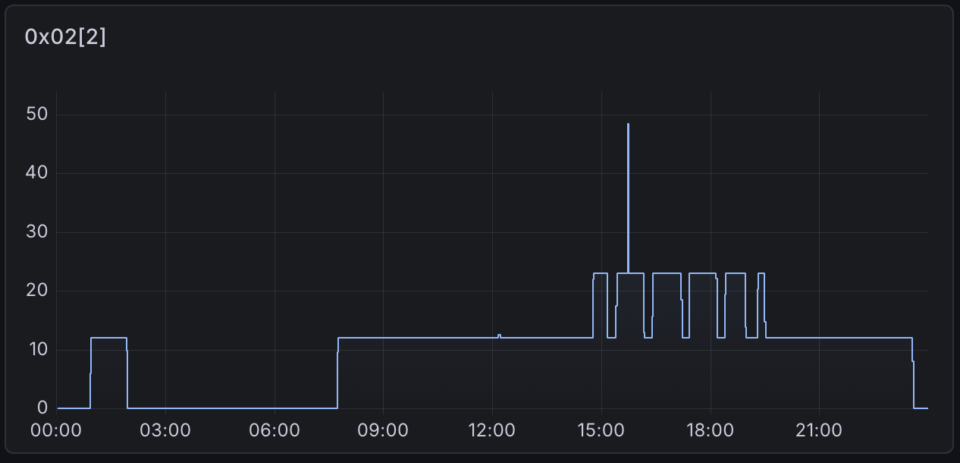
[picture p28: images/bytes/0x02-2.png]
| Chart (raw) |  |

#### Payload `0x02[3]`

| | |
|---|---|
| Meaning | Compressor frequency, actual (integer part) |
| HA Entity | `compressor_frequency_actual_int`, `compressor_frequency_actual_float` |
| Midea Code | Fr |
| Encoding | `b` Hz |
| Confidence | High |
| Evidence | Encoding reverse-engineered using Midea's Inverter Tester |
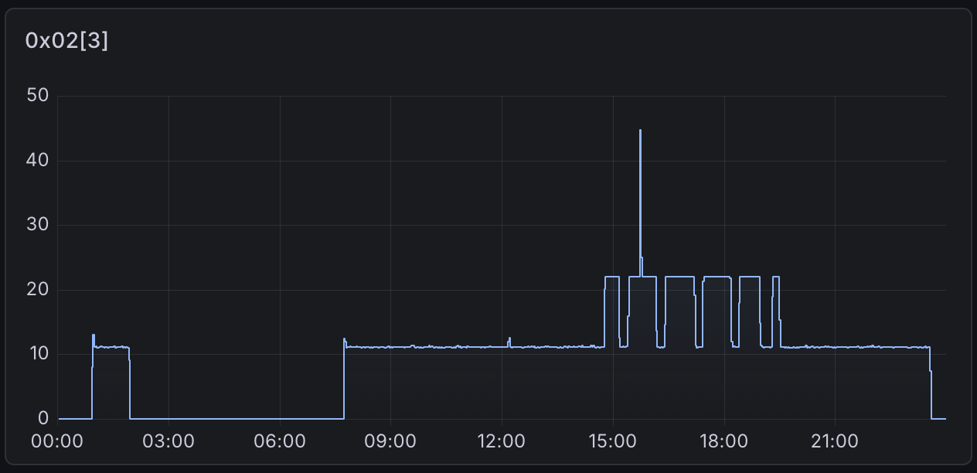
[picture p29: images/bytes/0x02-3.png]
| Chart (raw) |  |

#### Payload `0x02[4]`

| | |
|---|---|
| Meaning | Error codes |
| HA Entity | `error_code_1` |
| Midea Code | E3, E0, P8, Eb, P6, PA, L3, L0 |
| Encoding | bit 0 = E3 / Indoor fan speed outside of normal range<br>bit 1 = E0 / Indoor unit EEPROM parameter error<br>bit 2 = P8 / Outdoor current protection<br>bit 3 = Eb / Display board communication failure<br>bit 4 = P6 / Compressor discharge temperature protection<br>bit 5 = PA / Condenser high temperature protection<br>bit 6 = L3 / Frequency limit caused by current<br>bit 7 = L0 / Frequency limit caused by low/high indoor coil temperature |
| Confidence | High |
| Evidence | Encoding reverse-engineered using Midea's Inverter Tester |
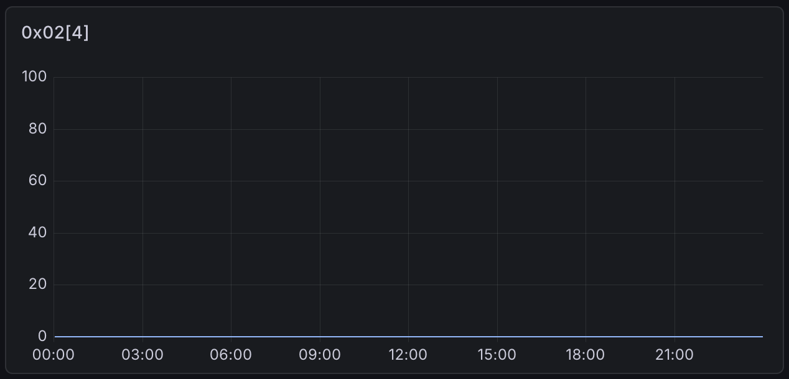
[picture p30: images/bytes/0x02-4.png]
| Chart (raw) |  |

#### Payload `0x02[5]`

| | |
|---|---|
| Meaning | Error codes |
| HA Entity | `error_code_2` |
| Midea Code | E60, E61, L2, E2, E1, L1, P90, P91 |
| Encoding | bit 0 = E60 / Indoor ambient temperature sensor (T1) failure (open or short circuited)<br>bit 1 = E61 / Indoor coil temperature sensor (T2) failure (open or short circuited)<br>bit 2 = L2 / Frequency limit caused by discharge temperature (TP)<br>bit 3 = E2 / Zero-crossing signal detection error<br>bit 4 = E1 / Communication error between indoor and outdoor unit<br>bit 5 = L1 / Frequency limit caused by outdoor coil temperature (T3)<br>bit 6 = P90 / Evaporator coil high temperature protection<br>bit 7 = P91 / Evaporator coil low temperature protection |
| Confidence | High |
| Evidence | Encoding reverse-engineered using Midea's Inverter Tester |
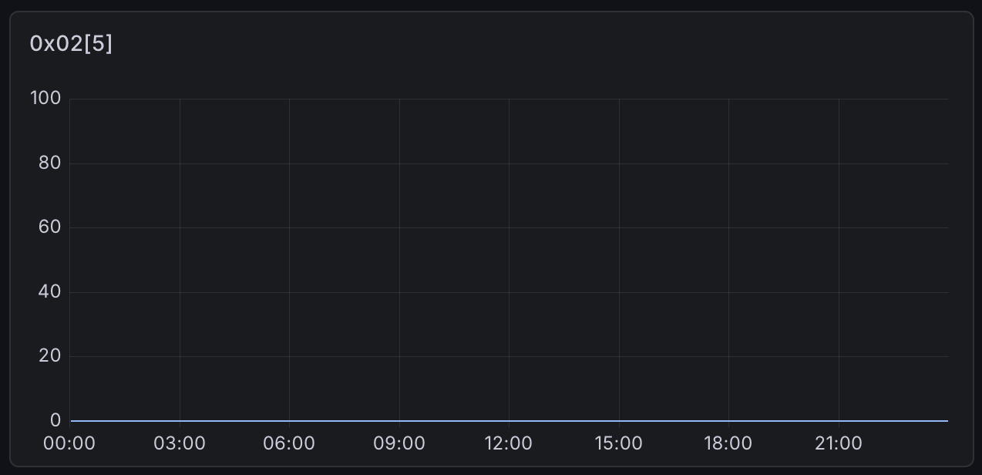
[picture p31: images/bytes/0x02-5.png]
| Chart (raw)  |  |

#### Payload `0x02[6]`

| | |
|---|---|
| Meaning | Error codes |
| HA Entity | `error_code_3` |
| Midea Code | E80, E81, E1, E83, P0, P1, E5, P8 |
| Encoding | bit 0 = E80<br>bit 1 = E81<br>bit 2 = E1 / Communication error between indoor and outdoor unit<br>bit 3 = E83<br>bit 4 = P0 / IPM malfunction or IGBT current protection<br>bit 5 = P1 / Voltage protection<br>bit 6 = E5 / Sensor failure<br>bit 7 = P8 / Outdoor current protection |
| Confidence | High |
| Evidence | Encoding reverse-engineered using Midea's Inverter Tester |
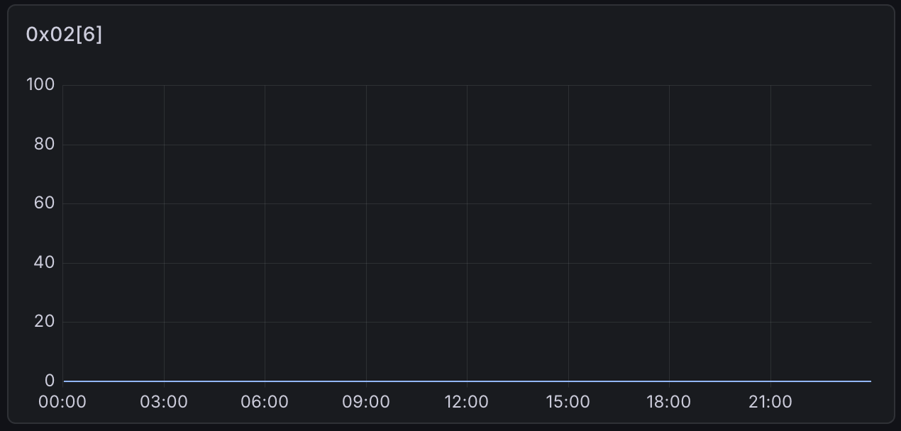
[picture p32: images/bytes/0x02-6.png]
| Chart (raw) |  |

#### Payload `0x02[7]`

| | |
|---|---|
| Meaning | Error codes |
| HA Entity | `error_code_4` |
| Midea Code | P4, P6, PA, L5, L3, L2, E7 |
| Encoding | bit 0 = P4 / Compressor feedback protection<br>bit 1 = P6 / Compressor discharge temperature protection<br>bit 2 = PA / Condenser high temperature protection<br>bit 3 = L5 / Frequency limit caused by voltage<br>bit 4 = L3 / Frequency limit caused by current<br>bit 5 = L2 / Frequency limit caused by discharge temperature (TP)<br>bit 6 = E7 / Outdoor fan speed outside of normal range<br>bit 7 = na / inverter tester shows blank screen when bit is set |
| Confidence | High |
| Evidence | Encoding reverse-engineered using Midea's Inverter Tester |
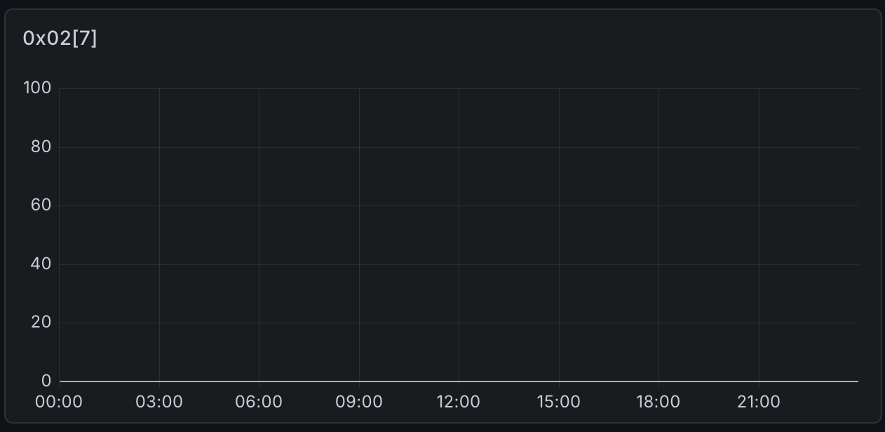
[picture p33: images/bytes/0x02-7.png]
| Chart (raw) |  |

#### Payload `0x02[8]`

| | |
|---|---|
| Meaning | Operating mode |
| HA Entity | `operating_mode` |
| Midea Code | — |
| Encoding | 0 = OFF<br>1 = COOL<br>2 = HEAT<br>3 = ONLY FAN<br>4 = DRY<br>5 = RESERVED<br>6 = FORCE COOL<br>7 = DEFROST |
| Confidence | High |
| Evidence | Encoding reverse-engineered using Midea's Inverter Tester Manual |
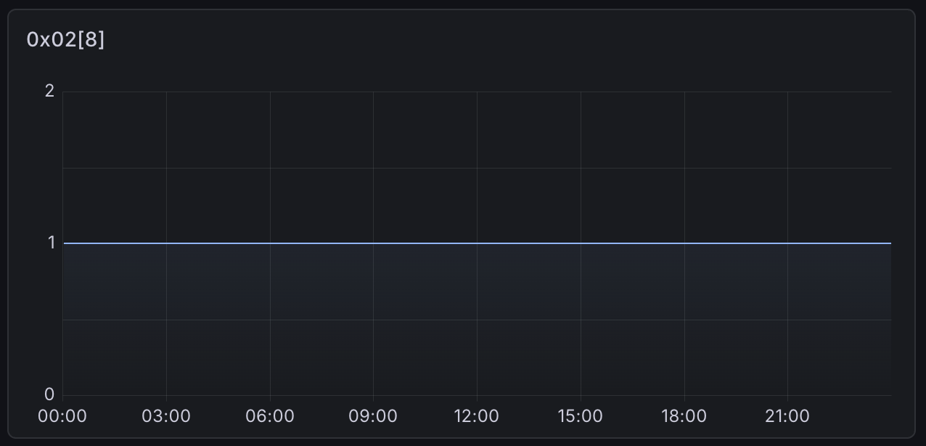
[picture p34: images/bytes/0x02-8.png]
| Chart (raw) |  |

### Response Type `0x03`

#### Payload `0x03[2]`

| | |
|---|---|
| Meaning | Indor run status / bit1 : turbo |
| HA Entity | — |
| Midea Code | — |
| Encoding | |
| Confidence | Low |
| Evidence | [forum](https://community.home-assistant.io/t/1015912/99) |
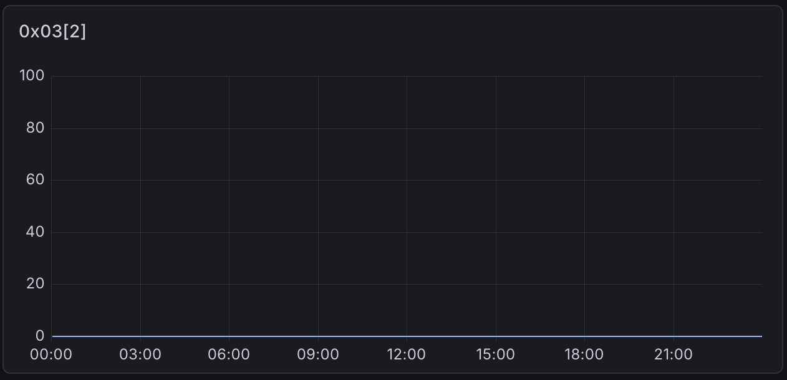
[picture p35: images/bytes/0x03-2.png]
| Chart (raw) |  |

#### Payload `0x03[3]`

| | |
|---|---|
| Meaning | — |
| HA Entity | — |
| Midea Code | — |
| Encoding | — |
| Confidence | — |
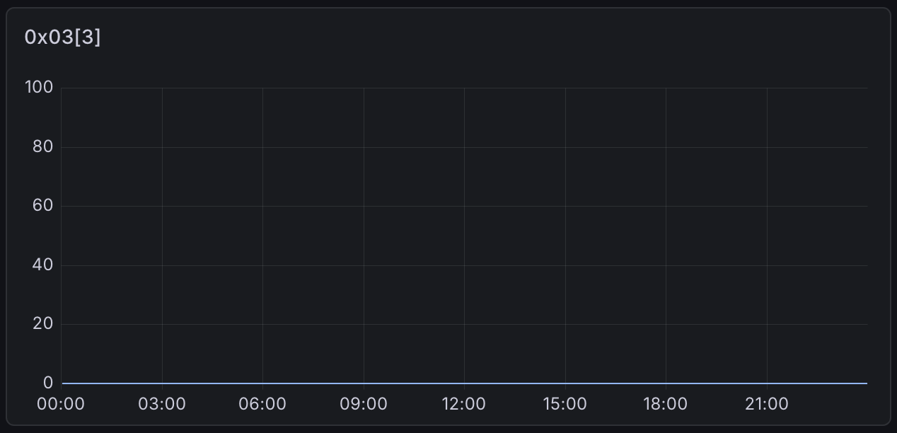
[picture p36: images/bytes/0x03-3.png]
| Chart (raw) |  |

#### Payload `0x03[4]`

| | |
|---|---|
| Meaning | EEV zone "row bound" |
| HA Entity | — |
| Midea Code | — |
| Encoding | — |
| Confidence | Low |
| Evidence | [forum](https://community.home-assistant.io/t/1015912/41) |
| Chart (raw) |  |

#### Payload `0x03[5]`

| | |
|---|---|
| Meaning | EEV zone "row index" |
| HA Entity | — |
| Midea Code | — |
| Encoding | — |
| Confidence | Low |
| Evidence | [forum](https://community.home-assistant.io/t/1015912/41) |
| Chart (raw) |  |

#### Payload `0x03[6]`

| | |
|---|---|
| Meaning | DC bus voltage |
| HA Entity | `dc_bus_voltage` |
| Midea Code | Uo |
| Encoding | `round(b · 59/32 − 1)` V |
| Confidence | Medium |
| Evidence | [forum](https://community.home-assistant.io/t/1015912/17) |
| Chart (raw) |  |

#### Payload `0x03[7]`

| | |
|---|---|
| Meaning | — |
| HA Entity | — |
| Midea Code | — |
| Encoding | — |
| Confidence | — |
| Chart (raw) |  |

#### Payload `0x03[8]`

| | |
|---|---|
| Meaning | — |
| HA Entity | — |
| Midea Code | — |
| Encoding | — |
| Confidence | — |
| Chart (raw) |  |

### Response Type `0x04`

#### Payload `0x04[2]`

| | |
|---|---|
| Meaning | Frequency-limit symbol bit field<br><br>Bit 7 = Frequency limit caused by communication error |
| HA Entity | — |
| Midea Code | — |
| Encoding | Bit field |
| Confidence | Low |
| Evidence | [forum](https://community.home-assistant.io/t/1015912/89) |
| Chart (raw) |  |

#### Payload `0x04[3]`

| | |
|---|---|
| Meaning | — |
| HA Entity | — |
| Midea Code | — |
| Encoding | — |
| Confidence | — |
| Chart (raw) |  |

#### Payload `0x04[4]`

| | |
|---|---|
| Meaning | — |
| HA Entity | — |
| Midea Code | — |
| Encoding | — |
| Confidence | — |
| Chart (raw) |  |

#### Payload `0x04[5]`

| | |
|---|---|
| Meaning | — |
| HA Entity | — |
| Midea Code | — |
| Encoding | — |
| Confidence | — |
| Chart (raw) |  |

#### Payload `0x04[6]`

| | |
|---|---|
| Meaning | Frequency-limit symbol bit field<br><br>Bit 4 = Frequency limit caused by low temperature of T2 |
| HA Entity | — |
| Midea Code | — |
| Encoding | Bit field |
| Confidence | Medium |
| Evidence | [forum](https://community.home-assistant.io/t/1015912/71) |
| Chart (raw) |  |

#### Payload `0x04[7]`

| | |
|---|---|
| Meaning | Compressor frequency, outdoor control |
| HA Entity | `compressor_frequency_outdoor_control` |
| Midea Code | — |
| Encoding | `b` Hz |
| Confidence | Medium |
| Evidence | None, this mapping is a guess |
| Chart (raw) |  |

#### Payload `0x04[8]`

| | |
|---|---|
| Meaning | Compressor frequency, indoor target (the IDU's request to the ODU) |
| HA Entity | `compressor_frequency_indoor_target` |
| Midea Code | oT |
| Encoding | `b` Hz |
| Confidence | Medium |
| Evidence | None, this mapping is a guess |
| Chart (raw) |  |

### Response Type `0x05`

#### Payload `0x05[2]`

| | |
|---|---|
| Meaning | Compressor frequency, actual (hundredths) |
| HA Entity | `compressor_frequency_actual_float` |
| Midea Code | Fr |
| Encoding | [`0x02[3]`](#payload-0x023) `+ b / 100` Hz |
| Confidence | Medium |
| Evidence | [forum](https://community.home-assistant.io/t/1015912/78) |
| Chart (raw) |  |

#### Payload `0x05[3]`

| | |
|---|---|
| Meaning | EEV zone command from the IDU. 0 means the IDU is not in control |
| HA Entity | — |
| Midea Code | — |
| Encoding | — |
| Confidence | Low |
| Evidence | [forum](https://community.home-assistant.io/t/1015912/41) |
| Chart (raw) |  |

#### Payload `0x05[4]`

| | |
|---|---|
| Meaning | — |
| HA Entity | — |
| Midea Code | — |
| Encoding | — |
| Confidence | — |
| Chart (raw) |  |

#### Payload `0x05[5]`

| | |
|---|---|
| Meaning | Moves on some units, with no proposed meaning |
| HA Entity | — |
| Midea Code | — |
| Encoding | — |
| Confidence | — |
| Evidence | [forum](https://community.home-assistant.io/t/1015912) |
| Chart (raw) |  |

#### Payload `0x05[6]`

| | |
|---|---|
| Meaning | — |
| HA Entity | — |
| Midea Code | — |
| Encoding | — |
| Confidence | — |
| Chart (raw) |  |

#### Payload `0x05[7]`

| | |
|---|---|
| Meaning | — |
| HA Entity | — |
| Midea Code | — |
| Encoding | — |
| Confidence | — |
| Chart (raw) |  |

#### Payload `0x05[8]`

| | |
|---|---|
| Meaning | — |
| HA Entity | — |
| Midea Code | — |
| Encoding | — |
| Confidence | — |
| Chart (raw) |  |

### Response Type `0x06`

#### Payload `0x06[2]`–`0x06[8]`

| | |
|---|---|
| Meaning | Always `0x00` on every unit reported so far |
| HA Entity | — |
| Midea Code | — |
| Encoding | — |
| Confidence | — |
| Chart (raw) |  |

The seven payload bytes share one block because no unit has ever reported any of them as non-zero.
Split them out if one starts to move.

## Encodings

The thermistor curves the temperature bytes use. `b` is the raw byte value.

### NTC thermistors

NTC β-model, rounded to the nearest 0.5 °C:

```
T = 1 / (1/298.15 + ln(0.81 · (255 − b) / b) / 4150) − 273.15
```

`0x00` and `0xFF` are fault codes. They read as −66 and 255.

### Discharge thermistor

`0x00[6]` (TP). Steinhart–Hart, rounded to the nearest 1 °C, with

```
L = ln((255 − b) / b)
T = 1 / (2.873×10⁻³ + 2.491×10⁻⁴ · L + 9.74×10⁻⁷ · L³) − 273.15
```

`0x00` is a fault code that reads as −48. `0xFE` and `0xFF` are fault codes passed through as-is.

## Keeping this file current

This file is the per-byte reference, so it has to change whenever a byte's meaning changes:

- **Adding, changing or removing a decode** in `MAPPED_PARAMS`
  ([midea_telemetry.cpp](components/midea_telemetry/midea_telemetry.cpp)): update the byte's block
  in the same PR. Name the sensor in **HA Entity** and give the conversion in **Encoding**, or set
  both back to `—` when a decode goes away. If the formula changed, update the Flux decode in the
  [Grafana dashboard](influxdb-grafana/README.md#how-a-panel-decodes) too.
- **A new proposal** from an issue, the forum or a log capture: put it in **Meaning**, set
  **Confidence** to `Low` or `Medium` and cite it in **Evidence**. Leave blocks with **Confidence**
  at `—` alone until someone proposes a meaning.
- **A proposal ruled out:** say so in **Evidence** and keep the link, so the same guess does not
  come back.
- **Any of the above:** update the byte's mark in the [Byte map](#byte-map) too.

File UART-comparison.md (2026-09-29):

## UART port comparison (Midea AC LAN)

The [Midea AC LAN](https://github.com/wuwentao/midea_ac_lan) integration sources a partially overlapping set of sensor data from the UART port located in the IDU. Tested using a MRCOOL DIY 12K 4th Gen 115V and the dongle that ships with a Midea U.

The UART port is more easily accessible than the test port on the ODU, which makes it attractive. Unfortunately, the data that is available seems to be highly model-dependent and too spotty to pursue this route further:

| Sensor | Test Port | UART | Comment |
|---|---|---|---|
| `indoor_ambient_temperature`  | ✅ | ✅ | |
| `indoor_coil_temperature` | ✅ | ✅ | |
| `outdoor_ambient_temperature` | ✅ | ✅ | |
| `outdoor_coil_temperature` | ✅ | ✅ | |
| `discharge_temperature` | ✅ | ❌ | |
| `ipm_temperature` | ❌ | ❌ | |
| `operating_mode` | ✅ | ✅ | |
| `compressor_frequency_outdoor_target` | ✅ | ❌ | |
| `compressor_frequency_actual_int` | ✅ | ✅ | |
| `outdoor_fan_speed` | ✅ | ❌ | |
| `eev_steps` | ✅ | ❌ | |
| `indoor_setpoint` | ✅ | ✅ | |
| `input_voltage` | ✅ | ❌ | |
| `current_draw` | ✅ | ❌ | |
| `dc_bus_voltage` | ✅ | ❌ | |
| `compressor_voltage` | ❔ | ✅ | candidate: 0x05 / byte 2 |
| `indoor_fan_speed_target` | ❌ | ✅ | |
| `indoor_fan_speed_actual` | ❌ | ✅ | |

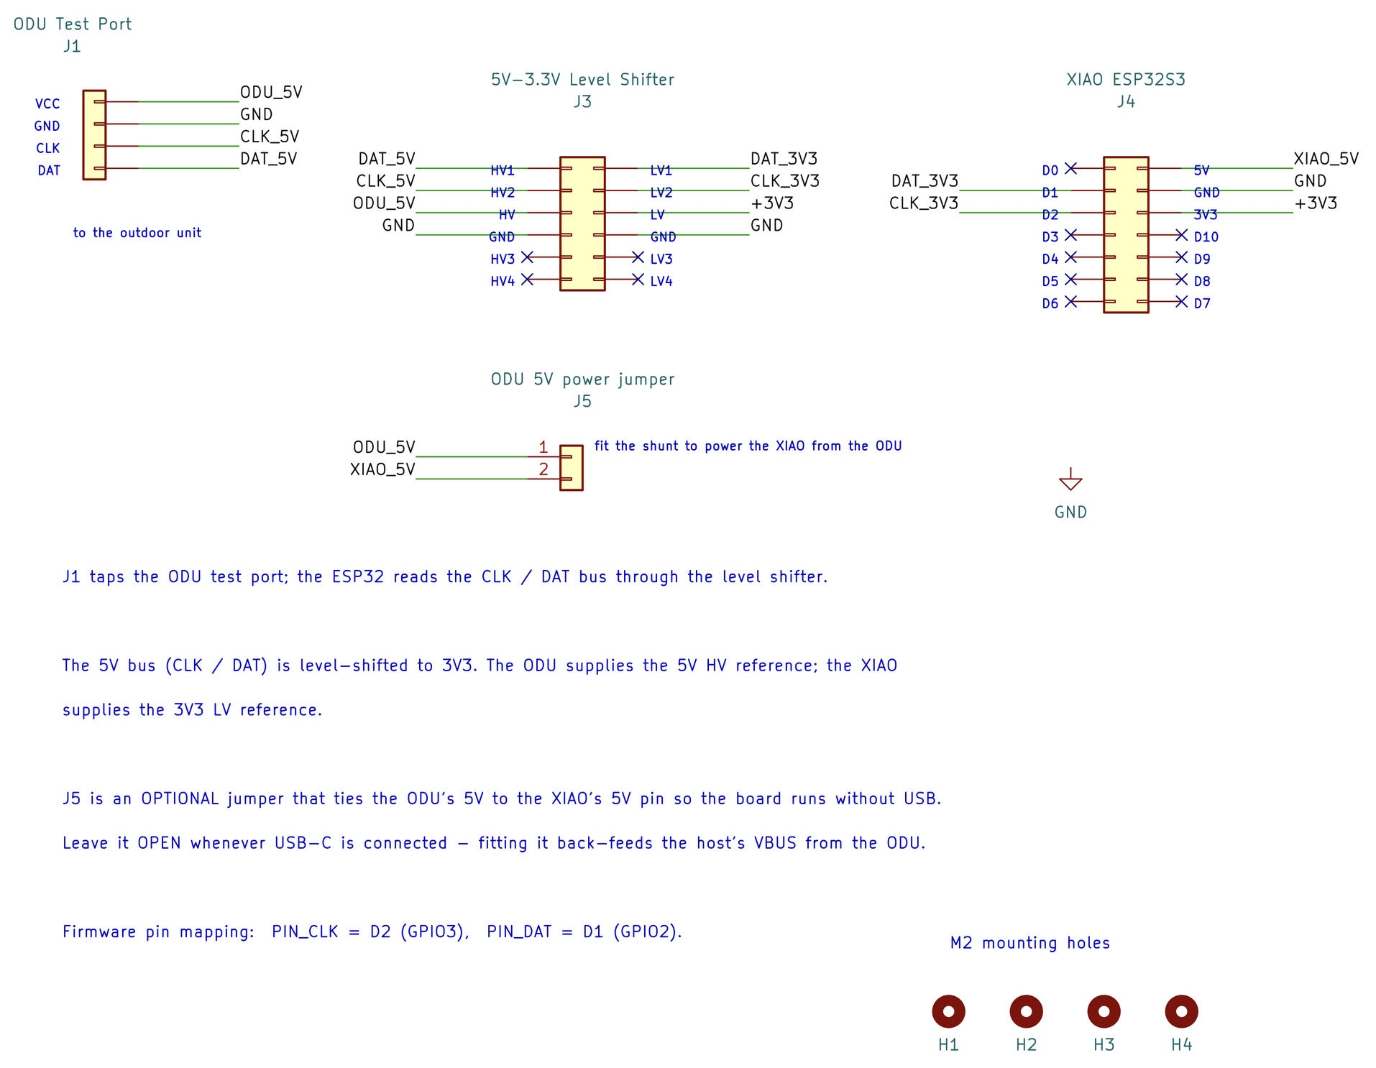
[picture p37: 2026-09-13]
pcb/schematic.png

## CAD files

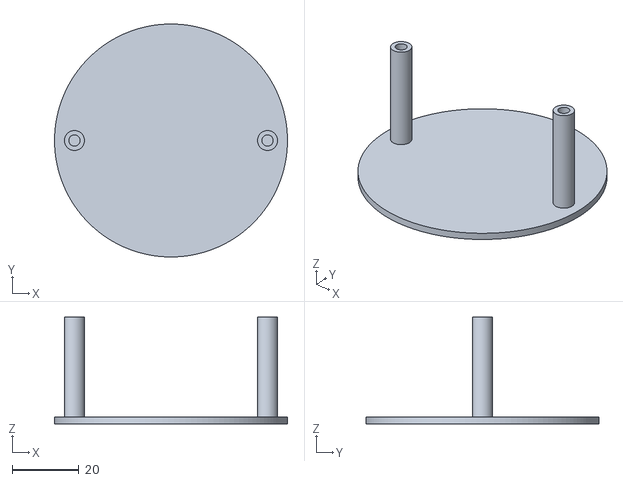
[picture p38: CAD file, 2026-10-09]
enclosure/soldering-mount-base.stl
70.0 x 70.0 x 32.0

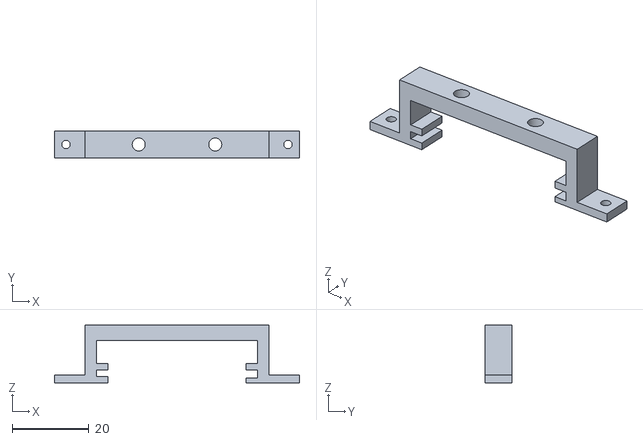
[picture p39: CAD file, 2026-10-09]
enclosure/soldering-mount-slider.stl
64.0 x 7.00 x 15.1

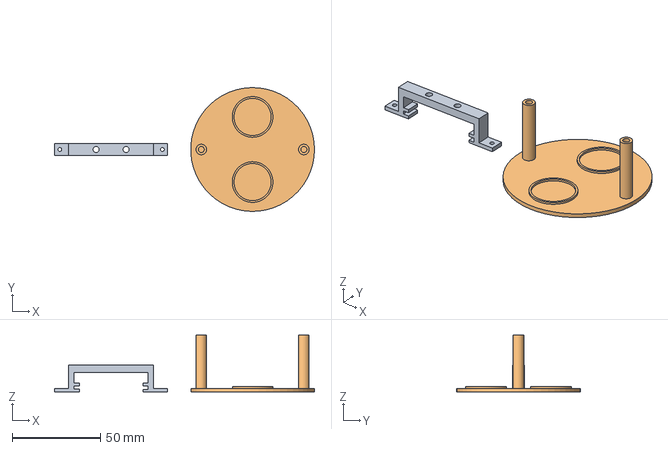
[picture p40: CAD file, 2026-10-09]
enclosure/soldering-mount.FCStd
147.0 x 70.0 x 32.0 mm
slider
base

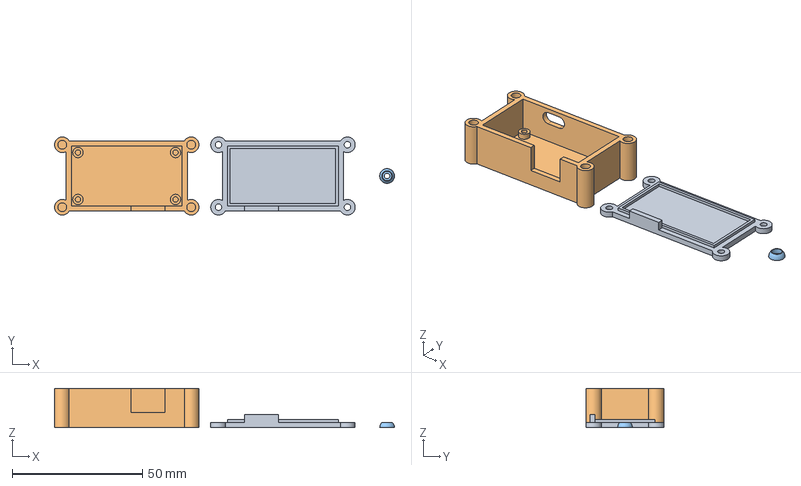
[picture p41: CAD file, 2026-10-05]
enclosure/enclosure.FCStd
130.6 x 30.0 x 15.0 mm
lid
base
spacer

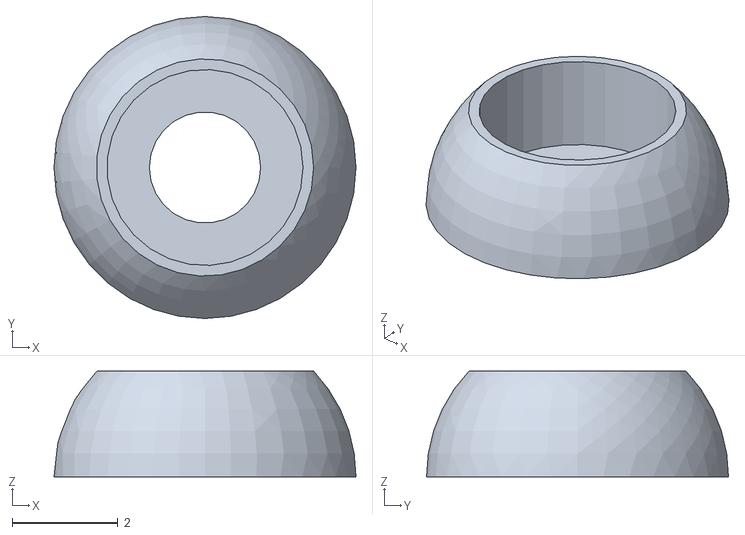
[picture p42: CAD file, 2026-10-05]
enclosure/enclosure-spacer.stl
5.70 x 5.70 x 2.00

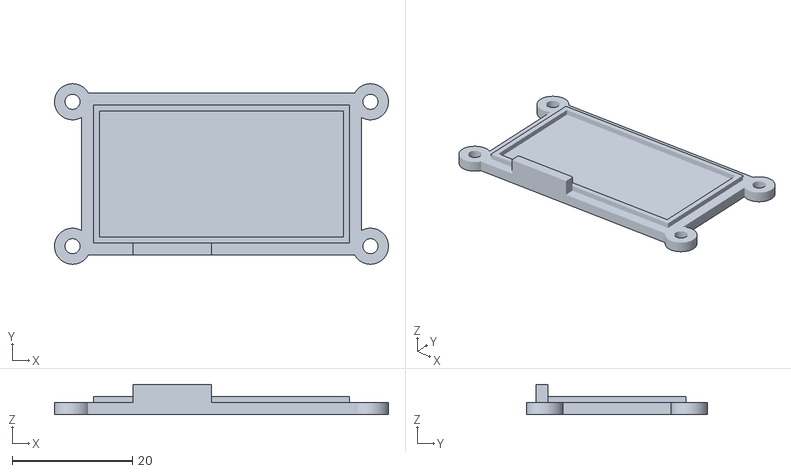
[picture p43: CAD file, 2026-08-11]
enclosure/enclosure-lid.stl
55.5 x 30.0 x 5.00

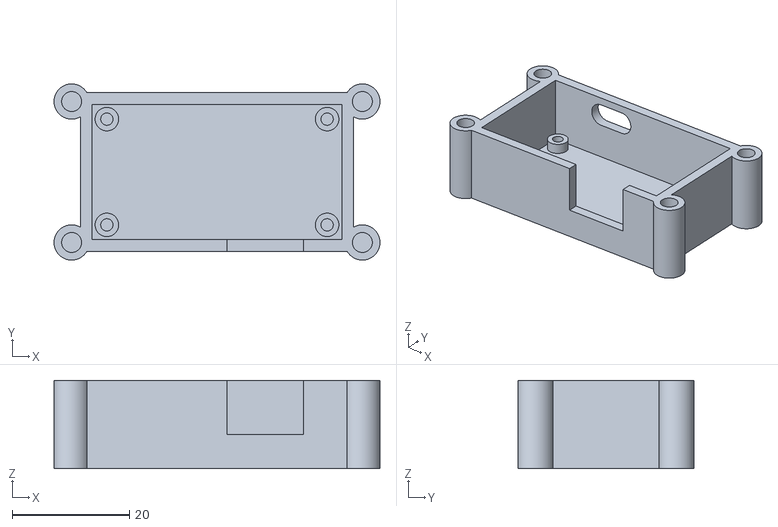
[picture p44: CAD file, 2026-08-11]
enclosure/enclosure-base.stl
55.5 x 30.0 x 15.0

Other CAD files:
enclosure/enclosure.3mf

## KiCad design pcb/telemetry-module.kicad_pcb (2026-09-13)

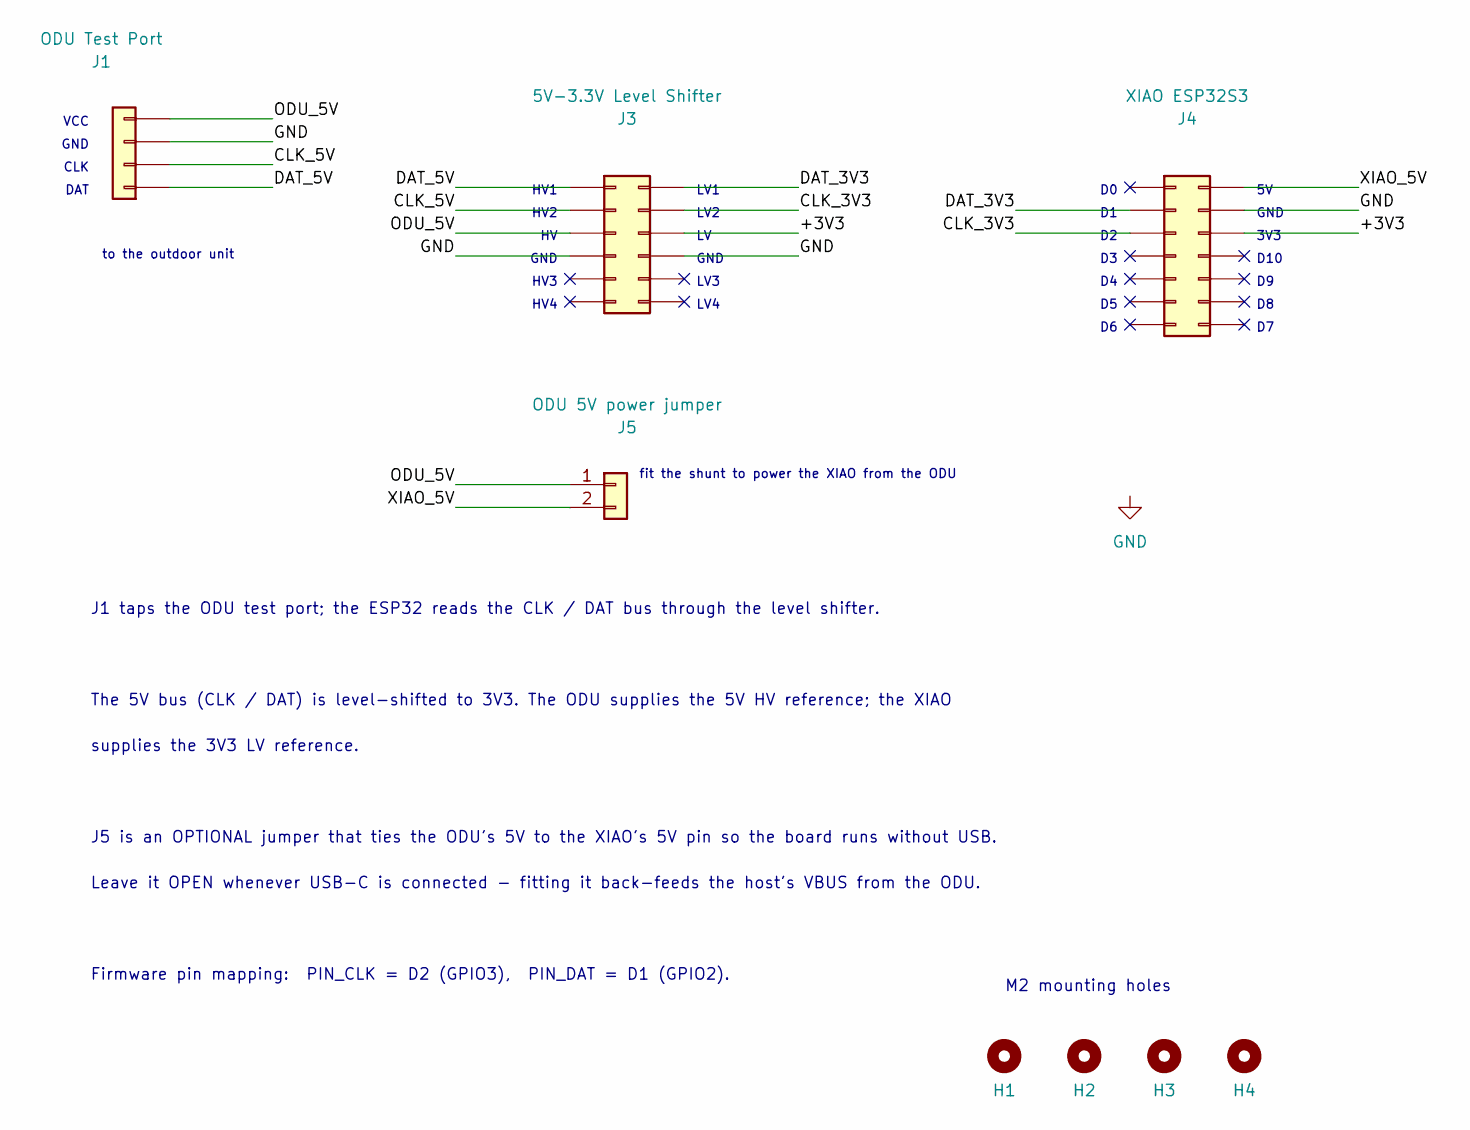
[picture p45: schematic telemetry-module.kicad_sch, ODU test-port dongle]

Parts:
H1, H2, H3, H4: MountingHole; MountingHole_2.2mm_M2
J1: ODU Test Port; JST_XH_B4B-XH-A_1x04_P2.50mm_Vertical
J3: 5V-3.3V Level Shifter; Module_LevelShifter_4ch_2x06_P2.54mm_RM10.16
J4: XIAO ESP32S3; Module_Seeed_XIAO_2x07_P2.54mm_RM15.24
J5: ODU 5V power jumper; PinHeader_1x02_P2.54mm_Vertical

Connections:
/+3V3: J3.6, J4.12
/CLK_3V3: J3.4, J4.3
/CLK_5V: J1.2, J3.3
/DAT_3V3: J3.2, J4.2
/DAT_5V: J1.1, J3.1
/ODU_5V: J1.4, J3.5, J5.1
/XIAO_5V: J4.14, J5.2
GND: J1.3, J3.7, J3.8, J4.13

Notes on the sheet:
to the outdoor unit
GND
CLK
fit the shunt to power the XIAO from the ODU
Leave it OPEN whenever USB-C is connected - fitting it back-feeds the host's VBUS from the ODU.
HV3
J1 taps the ODU test port; the ESP32 reads the CLK / DAT bus through the level shifter.
HV1
The 5V bus (CLK / DAT) is level-shifted to 3V3. The ODU supplies the 5V HV reference; the XIAO
HV4
DAT
M2 mounting holes
supplies the 3V3 LV reference.
LV3
LV4
3V3
VCC
LV2
J5 is an OPTIONAL jumper that ties the ODU's 5V to the XIAO's 5V pin so the board runs without USB.
D10
LV1
HV2
Firmware pin mapping: PIN_CLK = D2 (GPIO3), PIN_DAT = D1 (GPIO2).

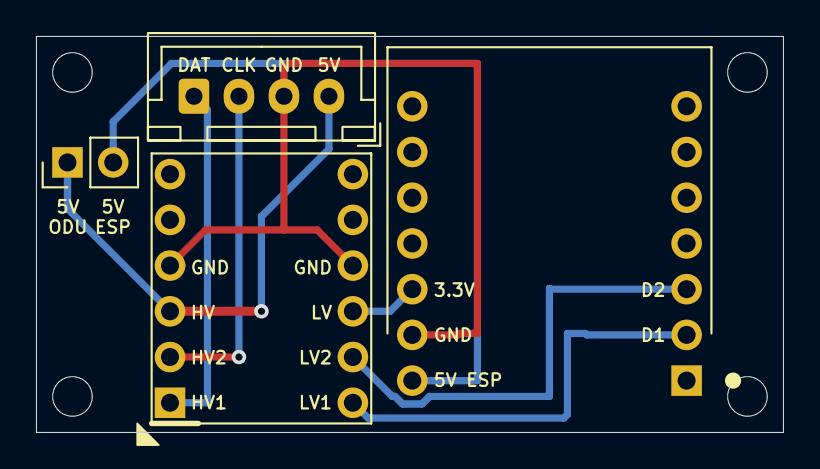
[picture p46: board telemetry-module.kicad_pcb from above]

Board: 2 copper layers, 41.5 x 22.0 mm, 8 parts (0 on the bottom side), 8 nets.

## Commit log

2026-07-22 initial commit for enclosure
    [enclosure-bottom.stl, enclosure.FCStd]
2026-07-22 more work on enclosure
    [enclosure-bottom.stl, enclosure-top.stl, enclosure.FCStd]
2026-07-25 added PCB files
    [enclosure-bottom.stl, enclosure-top.stl, enclosure.FCStd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]
2026-07-26 Issue 2: Support for the ESPHome WebServer component to expose all sensors + raw request/response bytes (#6)
2026-07-26 GH-0002: disable request / response sensors by default
2026-07-26 GH-0005: expose IPM Temperature
2026-07-26 GH-0005: expose DC bus voltage
2026-07-26 GH-0009: tooling to simplify mapping of additional sensors
2026-07-27 added disclaimer
    [diagnostic-port-dongle.kicad_pcb, diagnostic-port-dongle.kicad_sch]
2026-07-28 GH-0012: remove sensors for raw request bytes (#13)
2026-07-28 added UART comparison to README
2026-08-01 more work on PCB
    [diagnostic-port-dongle.kicad_pcb, telemetry-module.kicad_pcb, telemetry-module.kicad_sch]
2026-08-01 temporarily removed PCB section
2026-08-01 GH-0014: reduce size of PCB
    [enclosure-base.3mf, telemetry-module.kicad_pcb, telemetry-module.kicad_sch]
2026-08-03 GH-0019: Remove support for raw ODU responses as sensor
2026-08-03 GH-0020: Expose Wi-Fi signal strength as sensor (#22)
    Add ESPHome's native wifi_signal platform to the example config so the
    dongle reports RSSI, and document it in the README.
2026-08-05 Rework Grafana dashboard to mirror the Home Assistant layout
    Single-select Device dropdown, and one stat card per sensor in a 4-column
    grid (IDU / ODU / Compressor·EEV / Fan+Power) matching the HA dashboard.
    Temperatures converted C->F in Flux to read like HA.
2026-08-05 Cap stat value font size and add DC Bus Voltage card
    Stat panels were auto-scaling the value to fill the card; pin valueSize so
    the numbers read at a sane size. Rename "Voltage" -> "Input Voltage" and add
    a separate "DC Bus Voltage" card (dc_bus_voltage was already collected).
2026-08-05 Convert dashboard cards to timeseries for zoom + tooltips
    Switch all 13 sensor panels from stat to timeseries so drag-to-zoom, hover
    tooltips, and a synced crosshair work. Legend table shows Last/Min/Max to
    keep the current-value readout the stat cards had.
2026-08-05 Merge AC/DC bus voltage and match HA layout colors
    Combine input and DC bus voltage into one chart with per-series
    colors, and rearrange/recolor the remaining panels to mirror the
    Home Assistant dashboard.
2026-08-06 more work on the README & enclosure
    [enclosure-base.stl, enclosure.FCStd]
2026-08-06 more work on the enclosure
    [enclosure.FCStd]
2026-08-12 Add operating-mode card to Grafana dashboard (#26)
    * Add operating-mode card to Grafana dashboard
    Adds an "Operating Mode" section to the bundled Grafana dashboard: a stat
    card showing the current mode as a colored, labeled value (the analog of
    the Home Assistant mode card), plus a state-timeline showing mode history
    over the selected range. Both decode the raw operating_mode integer via
    shared value mappings (0=Off, 1=Cooling, 2=Heating, 3=Fan only,
    4=Dehumidify, 5=Reserved, 6=Forced cool, 7=Defrost).
    Also corrects the operating_mode code documentation in the README, which
    previously mislabeled 0 as cooling (0 is Off; 1 is Cooling).
    Closes #25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
2026-08-13 Add a card for the current set point & current indoor temperature to the Grafana dashboard. (#29)
    * Add current set point & indoor/outdoor temp cards to dashboard (#28)
    Restructure row 1 into six cards: Operating Mode, Current Set Point,
    Current Indoor Temperature, and Current Outdoor Temperature (each half
    width), followed by Operating Mode History and Set Point History.
    Split the combined AC / DC Bus Voltage panel into separate AC Voltage
    and DC Bus Voltage cards to keep the grid fully populated after moving
    Set Point up into row 1.
    * Combine paired stat cards and swap Current Draw / AC Voltage (#28)
    Merge Current Indoor and Curr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
2026-08-14 Add Y-Axis Scale dropdown to switch min-max / 0-max (#30) (#31)
    * Add Y-Axis Scale dropdown to switch min-max / 0-max (#30)
    Add a `ymin` custom template variable with two options: Min–Max
    (auto, empty value) and 0–Max (value 0). Wire it into every
    timeseries panel via `min: "${ymin}"` so the Y-axis floor can be
    toggled dashboard-wide.
    * Fix 0-Max toggle, clean legend names, rename ODU Fan Speed (#30)
    The previous approach bound the axis min to ${ymin}, but Grafana does
    not interpolate template variables in the numeric min field — it
    parsed to NaN and blanked every timeseries panel.
    Replace it with an invisible zero-anchor ser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
2026-08-15 Update diagnostic port description in README
    Clarified the location of the diagnostic port on the control board.
2026-08-19 Gate current_draw on compressor state (#16) (#32)
    * Gate current_draw on compressor state (#16)
    The 0x01[2] byte only carries a meaningful current reading while the
    compressor runs. When the unit is OFF or in FAN ONLY mode the byte sits
    at a per-unit floor (3 on the 115V MRCOOL, 0 on the 220V Cooper & Hunter)
    that the linear model misdecodes as ~1 A, when a Fluke 325 clamp meter
    shows only ~0.2 A.
    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
2026-08-19 restored generic name in sample config
2026-08-20 Enhance README with centrally ducted units info
    Updated description to include centrally ducted units.
2026-08-20 Moved Sensors section up
2026-08-20 Fix link reference in README for supported sensors
    Corrected link reference for supported sensors in README.
2026-08-20 Revise supported sensors table with byte mappings
    Updated the supported sensors table with new byte mappings.
2026-08-24 Revise compressor frequency mappings (issue #34) (#35)
    * Revise compressor frequency mappings (issue #34)
    Support byte sources from multiple response frames so a value can combine
    data across frames, then split the compressor-frequency reading into the
    five controller-specific values that need it.
    MappedParam: replace the single `type` + `bytes[]` (one shared frame) with a
    ByteRef{frame, byte} array. A new param_fresh() gates each value on all its
    source frames being fresh, and the /json source_bytes now reports the true
    per-byte frame - fixing the previously incomplete disclosure for cross-frame
    values (current_draw now lists both 0x01[2] and 0x02[3]).
    Compressor frequency (replaces comp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
2026-08-25 Raw-byte ingest and per-message byte explorer (issue #36) (#37)
    Drive the InfluxDB/Grafana lane off the raw frame bytes, so known sensors and
    unit-specific unknown bytes come from one source.
    Firmware
    - /json gains `odu_response_bytes`: each response frame as a per-byte decimal
    array, the indexable form Telegraf can pick bytes out of.
    - Rename the raw sections for parallel naming: `source_bytes` -> `sensor_bytes`
    and the new arrays as `odu_response_bytes`, alongside `sensors` /
    `odu_responses`. tools/monitor.py follows the rename.
    Telegraf
    - gen-telegraf-conf.sh generates the complete telegraf.conf from one DEVICES
    list, giving each dongle both a decoded `midea` input and a raw `mi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
2026-08-25 Add IPM Temperature panel to Grafana dashboard (issue #38) (#39)
    ipm_temperature was already decoded by the component and ingested by
    Telegraf, but had no panel, so the value was only reachable by querying
    InfluxDB by hand — even though influxdb-grafana/README.md already listed
    "discharge & IPM temps" as covered by the dashboard.
    Adds an IPM Temperature timeseries (panel id 26) in the free slot at
    x:18, y:22, next to EEV Opening Steps. Modelled on the Compressor
    Discharge Temperature panel: same C-to-F map(), legend/tooltip options
    and invisible refId Z zero-anchor series so the Y-Axis Scale (0-max vs
    min-max) variable applies here too.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
2026-09-05 Export the Grafana dashboard's data to CSV (issue #41) (#42)
    The dashboard was the only view onto the history InfluxDB collects. Getting
    that data out — for a spreadsheet, a notebook, a bug report — meant either
    hand-writing Flux in the Data Explorer or clicking Grafana's per-panel
    "Inspect -> Download CSV" once per chart, and the dashboard now carries 71
    charts per device (22 decoded + 49 raw-byte, from #36).
    tools/export-dashboard-data.py reuses the queries already version-controlled
    in the dashboard JSON: it substitutes the dashboard variables (bucket, device,
    frame, byte) and Grafana's v.timeRangeStart / v.timeRangeStop / v.windowPeriod
    macros, then runs the Flux against InfluxDB di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
2026-09-12 Annotate parameters with Midea service-manual codes (issue #43) (#44)
    The service manuals identify each parameter by a two-letter code, and the unit
    shows those codes on its own diagnostic display. Nothing here connected them to
    sensor names, so checking a reading on the display against the same reading in
    Grafana meant inferring the pairing from the label text.
    README.md gains a Code column on the sensor table, covering all 18 sensors.
    Three have no documented code (ipm_temperature, operating_mode,
    compressor_frequency_outdoor_control); those carry an em dash rather than an
    empty cell, so "no code exists" is distinguishable from an oversight.
    The dashboard prefixes the code onto the 15 si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
2026-09-12 Remove ipm_temperature (issue #45) (#46)
    The component decoded 0x01[4] through the NTC beta-model and published it as
    ipm_temperature: an ESPHome sensor, a /json key, an InfluxDB field, a Home
    Assistant entity, a Grafana panel (#39) and a byte label in the log viewer.
    Nothing establishes that 0x01[4] carries the IPM (power-module) temperature.
    The byte produces plausible-looking degrees under the NTC curve, which is the
    whole of the evidence for it. UART-comparison.md has meanwhile marked the
    sensor as absent in the Diagnostic Port column — contradicting the component
    that decodes it from that port. A named, unit-bearing sensor resting on a
    guess is worse than no sensor: it invites people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
2026-09-12 Optionally expose raw frame bytes as Home Assistant sensors (issue #47) (#48)
    The raw frame bytes had one consumer: /json -> Telegraf -> the midea_raw
    measurement -> the Grafana byte explorer (#36). That is the right tool for
    hunting a mapping across weeks of history, but it asks for Docker, InfluxDB,
    Telegraf and Grafana first. Home Assistant users saw only the decoded sensors,
    so every byte whose meaning is still unknown was invisible to exactly the
    people best placed to help identify it — someone with an unusual unit.
    Bytes 2-8 of all seven response frames (49 values) can now each be published
    to Home Assistant as-is, with no interpretation. Bytes 0/1/9 are framing
    (header, response ty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
2026-09-12 Update README to specify centrally ducted units
    Clarified the description of supported units by specifying 'centrally ducted units'.
2026-09-13 Add FRAME-BYTES.md: per-byte reference for every message type (issue #51) (#52)
    * Add FRAME-BYTES.md: per-byte reference for every message type (issue #51)
    What each frame byte means was spread across the firmware, the README
    sensor table, tools/logviewer.html, UART-comparison.md, closed issues
    and a forum thread, and those sources already disagree. The README is
    organised by sensor, so it cannot answer "what is 0x03[4]?".
    FRAME-BYTES.md lists every byte of the four requests and seven
    responses, each with a status that keeps facts and guesses apart:
    framing, decoded (a firmware sensor), hypothesis (proposed, not
    verified), unknown. Every hypothesis links to its evidence, and 0x01[4]
    keeps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
2026-09-13 Drive the whole Grafana dashboard off midea_raw bytes and retire RAW-BYTES.md (issue #53) (#54)
    * Drive the whole Grafana dashboard off midea_raw bytes, retire RAW-BYTES.md (issue #53)
    The dashboard charted the firmware-decoded `midea` measurement, so every
    value was frozen in the formula the firmware had when it was written: a
    corrected decode needed a reflash, and history could not be recomputed.
    The raw `midea_raw` stream, ingested alongside since #36, only fed the
    byte explorer.
    Dashboard: all 25 queries that read `midea` now filter the bytes they
    need from `midea_raw`, pivot them into one row per timestamp, apply the
    encoding from FRAME-BYTES.md, and name the series after the firmware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
2026-09-13 README: trim the raw frame bytes section to what users need (issue #55) (#56)
    After the YAML snippet, three paragraphs explained the raw byte
    sensors. Most of it either repeated what is right next to it or
    described schema internals:
    - the raw_0x<frame>_<byte> key pattern, which the snippet shows and the
    example YAML lists in full;
    - that bytes 0, 1 and 9 are framing, when the paragraph before already
    says bytes 2-8 and FRAME-BYTES.md covers framing;
    - state_class, no unit, and going unavailable when stale, which do not
    change what a user does and hold for every sensor;
    - RAM and flash figures, where "free unless enabled" is the only part
    that matters.
    One paragraph keeps the two p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
2026-09-13 Rename "diagnostic port" to "test port", Midea's name for it (issue #57) (#58)
    * Rename "diagnostic port" to "test port", Midea's name for it (issue #57)
    Midea calls the outdoor unit's 4-pin service connector the test port:
    it is labeled TEST on the control board. The repo called it the
    diagnostic port, which matches neither the board nor the service
    manuals, and the README said "diagnostic port" and "labeled TEST" in
    the same sentence.
    Test port now names the connector in README.md, UART-comparison.md
    (prose and column header), FRAME-BYTES.md, the MideaTelemetry class
    comment, the KiCad schematic (title block, J1 note, J1 value) and the
    PCB (J1 value). "Diagnostic bus" wording is rephrase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
    [telemetry-module.kicad_pcb, telemetry-module.kicad_sch]
2026-09-13 Upgrade Grafana from 11.3.0 to 12.4 (issue #59) (#60)
    * Upgrade Grafana from 11.3.0 to 12.4 (issue #59)
    grafana/grafana-oss:11.3.0 pinned an exact patch of a Grafana major
    that no longer gets security fixes, and the stack exposes Grafana's
    login on port 3000. The grafana-oss image name is also dead: Grafana
    stopped updating that repository at 12.4.0 and it has no 12.4 tags.
    Switch to grafana/grafana:12.4. It is the last 12.x minor, with
    security fixes until May 2027, and the floating minor tag picks them up
    on docker compose pull, as influxdb:2.7 and telegraf:1.32 already do.
    13.x is left for later because it saves dashboards in the v2 JSON
    format, which file provisioning rejects (grafana/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
2026-09-13 Upgrade Telegraf from 1.32 to 1.40 (issue #61) (#62)
    telegraf:1.32 was last pushed in June 2025, so the stack's collector has
    had no bug or security fixes for over a year. Move to telegraf:1.40, the
    current release line, keeping the floating minor tag so docker compose
    pull picks up 1.40.x patches, like influxdb:2.7 and grafana/grafana:12.4.
    Checked the changes since 1.32 against the generated telegraf.conf
    (inputs.http, parsers.json_v2 with explicit field entries,
    processors.dedup, outputs.influxdb_v2):
    - strict environment variable handling is the default since 1.38 and
    only allows variables in string values. The config uses exactly three
    (INFLUX_TOKEN, INFLUX_ORG, INFLUX_BUCKET), all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
2026-09-13 Upgrade InfluxDB from 2.7 to 2.9 (issue #63) (#64)
    influxdb:2.7 has not been updated on Docker Hub since May 2026. Move to
    influxdb:2.9 (currently 2.9.1), keeping the floating minor tag so docker
    compose pull picks up patches, like telegraf:1.40 and
    grafana/grafana:12.4. 2.9 hashes API tokens on disk, includes compaction
    reliability fixes, and ships Flux 0.200.0.
    The stack README gets an upgrade note: 2.9 reads existing data in place,
    and the image skips first-run setup when a database exists. Token
    hashing is one-way: tokens keep working, but the plaintext can no longer
    be read back and downgrading below 2.8 erases them, so keep .env. The
    note has a backup command that archives both volume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
2026-09-20 Expose the 0x02 error-code bytes as sensors and chart them (issue #67) (#68)
    Four new mapped sensors - error_code_1 through error_code_4 - carry the
    error bit fields 0x02[4] through 0x02[7] as the byte value. The bits are
    independent and several can be set at once, so decoding them into strings
    in the firmware would duplicate 31 code names that already live in
    FRAME-BYTES.md; the number keeps one source of truth.
    They are ordinary mapped params: one MAPPED_PARAMS entry each, NAN when
    frame 0x02 goes stale, and present in /json. Unlike the opt-in raw-byte
    sensors they are enabled in the example config and not Diagnostic, since
    a fault belongs on the device card.
    The dashboard gains an "Erro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
2026-09-20 Chart the error codes over time instead of showing a single value
    The four Error Codes panels were stat cards showing the latest byte. A
    single number says a fault is present but nothing about when it started
    or what the unit was doing at the time, which is the question a fault
    actually raises. They are now timeseries panels, styled like the rest of
    the dashboard, so a code lines up in time against the temperature,
    frequency and current charts above it.
    These four keep the *highest* sample per window rather than the last, the
    one deviation from every other panel. A bit field is not a quantity:
    `last` would drop a fault that set and cleared inside a window, and `mean`
    would invent byte value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
2026-09-20 Expand the error-code row by default and collapse the compressor row
    A fault that came and went is easy to miss behind a collapsed row, so the
    Error Codes row now opens with the dashboard. The extended compressor
    frequency charts move the other way and start collapsed.
    Grafana keeps an expanded row's panels as top-level siblings and a collapsed
    row's panels nested inside the row, so the panels move with the flags, and
    gridPos.y is re-flowed: the Error Codes row rises to y=31 and its panels to
    y=32, which leaves the Message row and byte explorer where they were.
2026-09-21 Add a byte map to FRAME-BYTES.md
    A type-by-index grid showing which response bytes are decoded, proposed
    or unknown, with each cell linking to the byte's section.
2026-09-21 Move the Error Codes row above the compressor frequency row
    The error codes are open by default, so they now sit right below the
    sensor charts. The collapsed Compressor Frequency (extended) row
    follows them, above the byte explorer.
2026-09-26 Update outdoor fan speed unit from raw to RPM
2026-09-27 more work on FRAME-BYTES.md
2026-09-29 Reinstate ipm_temperature (issue #70) (#71)
    Brings back the NTC beta-model decode of 0x01[4] that #46 removed.
    FRAME-BYTES.md has since gathered forum reports that the byte does carry
    the IPM temperature, at least on some units. Until now, reading it meant
    enabling raw_0x01_4 and converting the value by hand.
    The component side is a straight revert of #46: the MAPPED_PARAMS entry,
    the sensors[] slot and the LOG_SENSOR line in midea_telemetry.cpp, the
    setter and member in midea_telemetry.h, the schema in sensor.py and the
    example YAML. The entry goes back after discharge_temperature in both
    MAPPED_PARAMS and sensors[], so the static_assert pairing them still
    holds.
    The Grafana panel had to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
2026-09-29 add charts to FRAME-BYTES.md
2026-10-04 added spacer to enclosure
    [enclosure-spacer.stl, enclosure.3mf, enclosure.FCStd]
2026-10-06 Update README with sensor details and cleanup
    Clarified sensor information for ACiQ multi-zone units and removed optional raw frame bytes section.
2026-10-09 add FreeCAD files for soldering mount
    [soldering-mount-base.stl, soldering-mount-slider.stl, soldering-mount.FCStd]
